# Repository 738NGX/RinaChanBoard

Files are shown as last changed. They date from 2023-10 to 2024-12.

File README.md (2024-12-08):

# 璃奈板Project
“璃奈板”出自日本万代南梦宫集团旗下全媒体音乐偶像企划《LoveLive!虹咲学园学园偶像同好会》，是登场角色天王寺璃奈制作的舞台道具，可以在表演时随歌曲自动变换表情来向台下观众传达情感。本项目遵循AGPL-3.0协议开源，致力于面向LoveLive!系列企划粉丝打造一款能够完全还原动画中功能的、更加贴合用户实际使用需求的璃奈板产品。

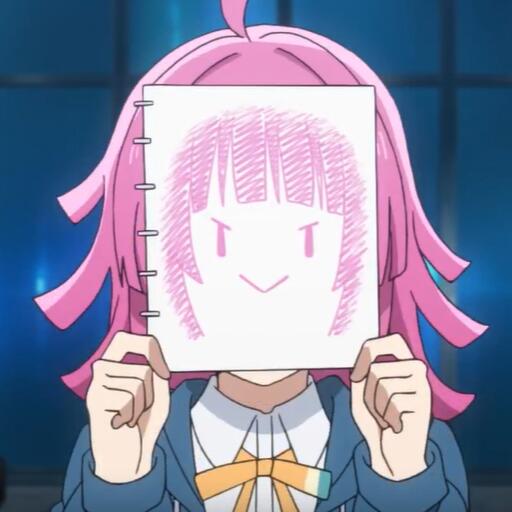
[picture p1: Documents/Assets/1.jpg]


## 🕊️ 项目进度

### 📝 计划中

- 下位机硬件驱动重写，着重性能提升。
- 3D外壳重建模。

### 🪲 进行中

- 文档补全中。
- Unity上位机（RinaChanBoardOperationCenter）编写中。
- 适用于ESP32的下位机（RinaChanBoardHardwareV2）编写中。

### ✅ 已完成

- 外壳3D打印试验。
- 主控、灯板PCB设计。
- 基于QT6.8.0的测试软件。
- ~~微信小程序上位机（RinaChanBoardOperationCenter.wechatapp）~~，已停止维护。
- ~~适用于ESP8266的下位机（RinaChanBoardHardware）~~，已停止维护。

## 🏠 文档导航

2. [总体设计](./Documents/2.总体设计.md)
3. [数据结构设计](./Documents/3.数据结构设计.md)
4. [通信报文设计](./Documents/4.通信报文设计.md)
5. [下位机系统功能设计](./Documents/5.下位机系统功能设计.md)
6. [上位机工具设计](./Documents/6.上位机工具设计.md)
7. [上位机组件设计](./Documents/7.上位机组件设计.md)
8. [上位机页面设计](./Documents/8.上位机页面设计.md)
9. [上位机资源数据](./Documents/9.上位机资源数据.md)

### 附录

- [附录1-口型同步](./Documents/附录1-口型同步.md)

## 📓 参考资料

(日本✌的开发博客)[NSmagnets - Qiita](https://qiita.com/NSmagnets)

(flyAkari版方案:ESP8266&Arduino+Android)[flyAkari/RinaChanBoard(github.com)](https://github.com/flyAkari/RinaChanBoard/tree/main)

(灯神)[我的颜色也是彩虹的一色！我与璃奈板 - 哔哩哔哩 (bilibili.com)](https://www.bilibili.com/read/cv9616845/)

(无敌扎蹄)[【天王寺科技】璃奈板的制作过程_哔哩哔哩_bilibili](https://www.bilibili.com/video/BV12b4y1t746/)

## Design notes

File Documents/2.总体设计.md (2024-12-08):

## 2. 总体设计

### 2.1 系统功能

整个项目系统可以被分为上位机和下位机两个子系统。每个子系统下又有各个细分模块。

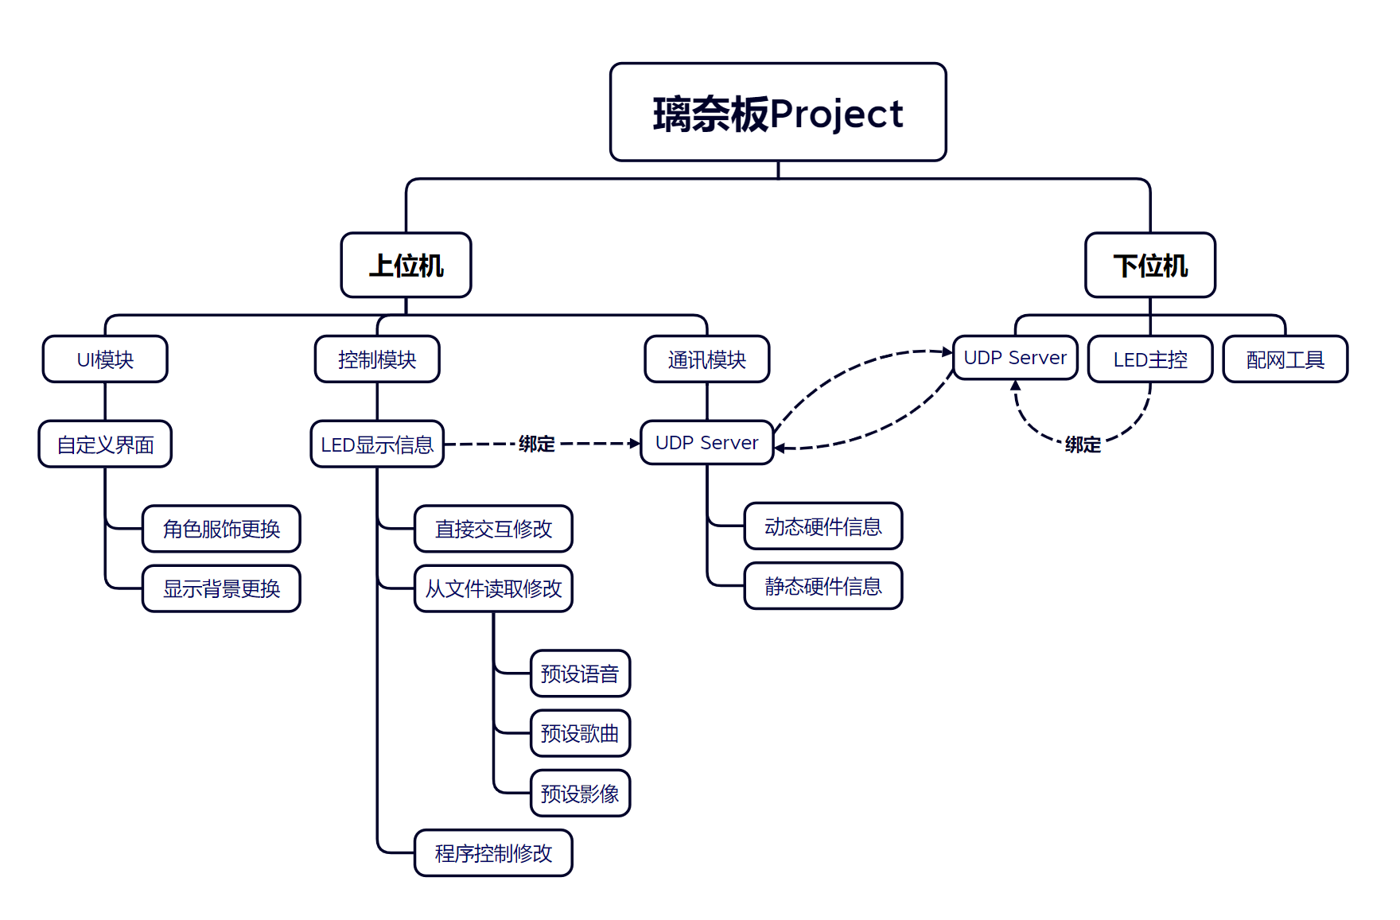
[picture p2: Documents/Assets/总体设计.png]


#### 2.1.1 上位机功能

实现上位机功能的载体为控制软件。

- **UI模块：**提供给用户自定义控制软件显示界面的功能。
- **控制模块：**提供了多种对LED显示信息的修改方法。
- **通讯模块：**提供了与下位机的通讯功能。

#### 2.1.2 下位机功能

实现下位机功能的载体为硬件驱动。测试软件亦可以模拟实现下位机的功能。

- **UDP Server：**提供与上位机的通讯功能。
- **LED主控：**提供对LED灯显示情况的控制功能。测试软件使用UI对LED灯显示情况进行模拟。
- **配网工具：**帮助下位机连接到指定的无线网络。测试软件直接使用主机网络的ip作为UDP Server地址，因而不包含此一功能。

### 2.2 系统软硬件平台

#### 2.2.1 系统开发平台

- **控制软件：**Unity 2022.3.15f1c1，API兼容级别`.NET Framework`直接使用或经过改写的第三方库如下：

    - **页面动画：**[Demigiant/dotween: A Unity C# animation engine. HOTween v2](https://github.com/Demigiant/dotween)
    - **口型同步：**[hecomi/uLipSync: MFCC-based LipSync plug-in for Unity using Job System and Burst Compiler](https://github.com/hecomi/uLipSync)

- **硬件驱动：**有第一代、第二代共两代驱动软件，分别适用于不同的硬件平台。硬件平台、板型、架构、使用库信息通过项目配置文件展示。

    - **RinaChanBoard Hardware：**PlatformIO Project

        ```ini
        [env:nodemcuv2]
        platform = espressif8266
        board = nodemcuv2
        framework = arduino
        monitor_speed = 9600
        lib_deps = 
        	fastled/FastLED@^3.6.0
        ```

    - **RinaChanBoard Hardware V2：**PlatformIO Project

        ```ini
        [env:esp32dev]
        platform = espressif32
        ;board = esp32dev
        board = esp32s3box
        framework = arduino
        monitor_speed = 115200
        monitor_rts = 0
        monitor_dtr = 0
        lib_deps = 
        	fastled/FastLED@^3.6.0
        	wnatth3/WiFiManager@^2.0.16-rc.2
        ```

- **测试软件：**C++20 & QT 6.8.0，使用Cmake编译（最低版本3.29）。

#### 2.2.2 系统运行平台

- **控制软件：**目前支持Windows和Android，计划支持iOS。

    | 操作系统                                    | 支持情况 | 备注                   |
    | ------------------------------------------- | -------- | ---------------------- |
    | Windows 7 (SP1+), Windows 10 and Windows 11 | ✅        |                        |
    | Android 10 或更高                           | ✅        | 目标架构为ARMv7和ARM64 |

- **硬件驱动：**两代硬件驱动的支持情况如下：

    | 驱动版本                  | Platform                 | Board               | 备注     |
    | ------------------------- | ------------------------ | ------------------- | -------- |
    | RinaChanBoard Hardware    | ESP8266（espressif8266） | nodemcuv2           | 不再维护 |
    | RinaChanBoard Hardware V2 | ESP32S（espressif32）    | esp32dev→esp32s3box |          |

- **测试软件：**Windows 7 (SP1+), Windows 10 and Windows 11。

### 2.3 关键技术

#### 2.3.1 无线通信

在本项目中，上位机和下位机之前的通讯使用**UDP协议**来完成。这是基于需要即时响应的需求，牺牲了一部分可靠性来换取更高的性能。基于硬件条件的限制，经过测试后，以**0.1s**作为UDP包发送和接收的最小间隔，称为1**帧（frame）**。UDP协议没有重传机制，当用户操作上位机发送离散控制信息时，需要用户自行确认硬件情况来检查包传送到位，如出现丢包需要用户重复操作来进行重传；当上位机程序发送连续控制信息时出现丢包不会进行重传，而是直接用后续的控制信息进行覆盖。

上位机和下位机需要在同一局域网下才能够进行通信，对应UDP Server的IP和端口情况如下表所示：

| 软件 | IP地址 | 端口 |
| --- | --- | ---- |
| 上位机-控制软件 | 主机本地IP地址 | 4321 |
| 下位机-硬件驱动 | 主控本地IP地址 | 1234 |
| 下位机-测试软件 | 主机本地IP地址 | 1234 |

具体的配网流程参见**[5.3 配网工具](./5.下位机系统功能设计)**章节；具体的上下位机通讯过程参见**[7.2 UDP服务](./7.上位机组件设计.md)**章节。

#### 2.3.2 口型同步

口型同步（LipSync）技术通过分析**梅尔倒谱系数（MFCC）**数据,解析音频中的元音信息（日语或汉语中的a、i、u、e、o），并且将其反应到璃奈板的口型上。在用户层面，该技术可以检测用户的麦克风输入来实时控制璃奈板的表情来模拟说话的效果。在开发者层面，该技术可以辅助编写时间轴文件，提升开发效率。

该部分内容较多，由于篇幅原因不在本篇文档展示，详情可查阅文档：**[附录1-口型同步](./附录1-口型同步.md)**。

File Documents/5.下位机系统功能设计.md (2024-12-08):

## 5. 下位机系统功能设计

实现下位机功能的载体为硬件驱动。测试软件亦可以模拟实现下位机的功能。本项目的下位机代码位于根目录的以下位置：

- ~~第一代硬件驱动：`RinaChanBoardHardware/RinaChanBoardHardware`~~ 弃用
- 第二代硬件驱动：`RinaChanBoardHardware/RinaChanBoardHardwareV2`
- 测试软件：`RinaChanBoardTester`

### 5.1 UDP Server

在硬件连接到网络后，下位机会自动在本地网络的1234端口启动一个UDP Server，准备监听从上位机发送的数据。监听的流程使用一个异步的协程`udpHandler`来实现，如下图所示：

```mermaid
sequenceDiagram
actor user as 用户 User
box 上位机
participant oc as 控制软件 OperationCenter
end
box 下位机
participant udp as UDP异步协程 udpHandler
participant leds as LED主控 leds
end
user->>oc: 用户控制上位机发送数据
oc->>udp:下位机接收来自上位机的数据包
activate udp
udp-->leds:handlePacket()开始
alt 包为PackTypeLen::FACE_FULL
    udp->>leds: 解码Face_Full报文并更新表情
else 包为PackTypeLen::FACE_LITE
    udp->>leds: 解码Face_Lite报文并更新表情
else 包为PackTypeLen::COLOR
    udp->>leds: 解码Color报文并更新颜色
else 包为PackTypeLen::BRIGHT
    udp->>leds: 解码Bright报文并更新亮度
else 包为PackTypeLen::REQUEST
    udp->>oc: 根据请求内容返回对应报文
end
udp-->leds:handlePacket()结束
deactivate udp
```

### 5.2 LED主控

UDP Server在判断出报文类型后，调用LED主控的函数来执行对应的操作，如下表所示：

| 报文 | 操作 |
| --- | --- |
| Face_Full报文/Face_Lite报文 | 解码为脸字符串后更新LED显示表情 |
| Color报文 | 解码为颜色数据后更新LED的显示颜色 |
| Bright报文 | 解码为亮度数据后更新LED的显示亮度 |
| 请求报文 | 将当前LED的对应显示信息编译为报文传回上位机 |

针对LED的控制主要依赖`<FastLED.h>`库。该库可以对所有灯珠的亮度进行整体控制，也可以对每个灯珠的颜色进行单独控制。该库中灯珠颜色的表示类型为`CRGB`，`CRGB::Black`表示灯珠熄灭，主要依靠这个来判断LED的开闭情况。

### 5.3 配网工具

硬件驱动借助了[tzapu/WiFiManager: ESP8266 WiFi Connection manager with web captive portal](https://github.com/tzapu/WiFiManager)库来帮助主控芯片连接到WIFI网络，配网的流程如下图所示：

```mermaid
sequenceDiagram
actor user as 用户 User
participant lan as 局域网 LAN
create participant main as 下位机主进程 Main
user->>main:硬件开机
participant flash as 主控闪存 Flash
main->>flash:查询是否存储了WIFI信息
alt 闪存中有存储WIFI信息
	main->>lan:尝试按照存储的WIFI名、密码连接到目标网络
	opt 连接成功
		main->lan:启用UDP Server监听
		Note over main,lan:成功连接，可以跳过后续配网流程
	end
else 进入配网流程
	loop 当配网未成功时
        create participant wm as 配网工具 WifiManager
        main->>wm:启用配网工具
        wm->>lan:扫描所有可以连接的WIFI网络
        create participant ap as 板载热点 AP
        wm->>ap:启用软AP热点
        wm->>ap:启用HTTP Server
        activate ap
        user->>ap:用户连接热点，选择WIFI并输入密码
        deactivate ap
        ap->>wm:记录用户输入信息
        destroy ap
        wm-xap:关闭软AP热点
        wm->>lan:根据用户输入信息尝试连接到目标网络
    end
    wm->>flash:存储WIFI信息以供下次开机时使用
    destroy wm
    main-xwm:结束配网
    main->lan:启用UDP Server监听
	Note over main,lan:成功连接
end
```

璃奈板硬件配备的网卡有两种模式：**基站模式（STA模式）**和**接入点模式（AP模式）**。STA模式下璃奈板与一般的主机一样连接到WIFI网络，并可以与同网络下的其他终端进行通信；AP模式下璃奈板自身会提供一个WIFI接入点供其他终端进行连接，承担类似于路由器或者手机热点的角色。璃奈板的配网逻辑基于这两种模式之间的切换。

璃奈板通电后首先进入到STA模式，尝试连接上次开机时连接到的网络。如果不能够成功连接，那么系统将会切换到AP模式，启动一个名为*RinaChanBoard*的WIFI热点，并且在`192.168.11.13`的地址启动一个HTTP Server作为配网的UI界面。当其他终端连接到该热点后即自动跳转到该页面。页面将会显示设备扫描到的所有可连接的WIFI网络（仅支持AP频段为**2.4GHz**频段的WIFI网络），随后用户可以直接选择并且输入密码信息。璃奈板确认WIFI名称和密码后会切换到STA模式尝试连接，如果成功连接，则配网流程结束，系统会存储下WIFI的名称和密码以供下次开机时再次连接使用；如果连接失败，系统切换回AP模式，重新开始配网流程。

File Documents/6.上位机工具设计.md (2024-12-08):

## 6. 上位机工具设计

在本项目中，所有的工具代码位于根目录`${OC}/Assets/Scripts/DataStructs`。

### 6.1 数据库工具`DatabaseTool`

静态类型`DatabaseTool`提供了一系列方法来将json文件序列化为实现了`IDatabase`接口的数据结构。json文件的序列化主要依赖`Newtonsoft.Json`库来实现。

#### 6.1.1 通用模板序列化函数

```c#
public static Dictionary<int, T> BuildDatabase<T>(string src) where T : IDatabase {...}
```

用户传入数据结构类型和json文件路径后，函数会返回一个静态字典数据库。字典的键为数据结构类型的`Id`属性，字典的值为数据结构类型本身。

#### 6.1.2 时间轴序列化函数

由于记录时间轴的json文件并不包含`Id`信息，所以序列化时间轴的函数需要调用媒体信息数据并从中获取`Id`作为字典的键。根据不同的媒体类型分别拆分成了三个独立的函数来实现功能：

```c#
public static Dictionary<int, TimeLine> BuildVoiceTimelineDatabase() {...}
public static Dictionary<int, TimeLine> BuildMusicTimelineDatabase() {...}
public static Dictionary<int, TimeLine> BuildVideoTimelineDatabase() {...}
```

函数的实现逻辑如下图所示：

```mermaid
flowchart LR
0([函数入口])-->1[调取媒体信息数据]-->2[遍历媒体信息]-->3[尝试根据媒体信息\n读取json文件]
3--读取成功-->4[构建时间轴数据\n将键值对写入字典]-->6[/遍历是否结束?/]
3--读取失败-->5[跳过该条媒体信息\n控制台记录日志]-->6--是-->7([返回字典结果])
6--否-->2
```

#### 6.1.3 ASCII序列化函数

```c#
public static Dictionary<string, Ascii> BuildAsciiDatabase() {...}
```

其实现逻辑上与通用模板序列化函数一致，区别在于其使用的键是字符`Symbol`而非`Id`，因而也单列一个函数。

### 6.2 媒体工具`MediaTool`

静态类型`MediaTool`主要保存了一系列媒体信息数据字典和时间轴数据字典，同时还提供了一个方法来将帧号转换为分秒格式的字符串。

#### 6.2.1 媒体信息数据字典

```c#
public static readonly Dictionary<int, VoiceInfo> voiceInfos;	// 语音信息
public static readonly Dictionary<int, MusicInfo> musicInfos;	// 歌曲信息
public static readonly Dictionary<int, VideoInfo> videoInfos;	// 影像信息
```

#### 6.2.2 时间轴数据字典

```c#
public static readonly Dictionary<int, TimeLine> voiceTimeLines;	// 语音时间轴
public static readonly Dictionary<int, TimeLine> musicTimeLines;	// 歌曲时间轴
public static readonly Dictionary<int, TimeLine> videoTimeLines;	// 影像时间轴
```

#### 6.2.3 时间戳转换函数

```c#
public static string ConvertFramesToTime(float frames) {...}
```

- 参数：帧号`frame`
- 返回：时间戳字符串

在播放歌曲和影像时用于进度条UI的数字时间戳显示。

### 6.3 LED工具`LedTool`

静态类型`LedTool`主要用于辅助实现一些灯光控制的功能。

#### 6.3.1 映射表`ledMap`

用于将`FaceString`的每一位映射到对应Id的LED灯珠上。映射过程在前文已有提及，不再重复阐释。

#### 6.3.2 预设颜色

预设颜色包括默认颜色以及LoveLive!五代团的所有角色、小组、团体应援色。数据分别存储在两个二维列表中：

- `colorName`：预设颜色对应的角色名或小组名；
- `colorValue`：预设颜色对应的十六进制RGB数值；

#### 6.3.3 点阵信息

点阵信息主要用于修改特定区域的LED灯珠显示情况，包括表情模块点阵`faceModules`和ASCII字符点阵`asciis`。

#### 6.3.4 转换函数

转换函数主要用于一些数据之间的互相转换。

- **十六进制/二进制字符串互转：**`HexToBinary`和`BinaryToHex`。
- **十六进制字符串/`Unity.Color`互转：**`HexToColor`和`ColorToHex`。
- **十六进制字符串/bytes数组互转：**`HexToBytes`和`BytesToHex`。

### 6.4 口型同步工具`RinaLipSync`

详情可查阅文档：**[附录1-口型同步](./附录1-口型同步.md)**。

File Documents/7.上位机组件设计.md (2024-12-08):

## 7. 上位机组件设计

在本项目中，所有的组件代码位于根目录`${OC}/Assets/Scripts/Components`。所有组件均继承自`MonoBehaviour`类。

### 7.1 LED组件`Leds`

该组件主要控制上位机上有关LED显示情况的UI部分。

#### 7.1.1 属性

| 属性名 | 类型 | 访问性 | 说明 |
| --- | --- | --- | --- |
| `CanCustom` | bool | public get; public set;  | 为true时可以单击对应的灯珠UI来切换开闭状态 |
| `WaitColorUpdate` | bool | public get; public set;  | 为true时触发页面颜色信息更新回调 |
| `Brightness` | int | public get; public set;  | 表示灯珠亮度 |
| `LedOnColor` | Color | public get; private set; | 表示灯珠开启的颜色 |
| `LedOffColor` | Color | private get; | 表示灯珠关闭的颜色 |
| `leds` | List | private get; | 灯珠UI列表 |
| `faceString` | StringBuilder | private get; | 脸字符串 |

#### 7.1.2 方法

```mermaid
flowchart TD
classDef extra fill:#fff;
classDef private fill:#ffa;

0[UpdateFaceModule\n更新表情模块]:::private
14(leds):::private
15(faceString):::private
0--修改-->14
0--修改-->15

1[UpdateColor\n更新LED显示颜色]--修改-->13(LedOnColor)
1--修改-->14
2[ClearFace\n清空显示表情]--修改-->14
2--修改-->15
3[UpdateFace\n根据Face更新表情显示]
3--依赖-->4[UpdateCheek\n更新脸颊模块]--依赖-->0
3--依赖-->5[UpdateLeftEye\n更新左眼模块]--依赖-->0
3--依赖-->6[UpdateRightEye\n更新右眼模块]--依赖-->0
3--依赖-->7[UpdateMouth\n更新嘴巴模块]--依赖-->0
8[SwitchLed\n切换单个LED开闭情况]--依赖-->16(LedTool.ledMap):::extra
0--依赖-->16
0--依赖-->17(LedTool.faceModules):::extra
8--修改-->14
8--修改-->15
9[UpdateLedsByString\n根据脸字符串更新表情显示]--依赖-->11[LedTool.HexToBinary]:::extra
9--修改-->14
9--修改-->15
10[EncodeFace\n将当前表情编码为脸字符串]--依赖-->12[LedTool.BinaryToHex]:::extra
10--依赖-->15
```

该组件的方法依赖和修改关系如上图所示，以下为图例说明，后文相关图片亦参照此图例：

- 直角矩形：表示方法
- 圆角矩形：表示属性
- 绿色：表示公有成员
- 黄色：表示私有成员
- 白色：表示外部成员

### 7.2 UDP服务`UdpServer`

该组件主要实现与下位机的通讯功能，几乎所有的模块都或多或少依赖该组件。由于UDP协议实际上没有如同TCP协议的建立连接过程，因而下文表述中的“连接”均为一种**伪连接**，代表UDP服务已经能够确定下位机的IP地址并且向该地址发送数据包，而不是真正意义上的TCP协议规定的连接。

#### 7.2.1 属性

| 属性名 | 类型 | 访问性 | 说明 |
| --- | --- | --- | --- |
| `IsConnected` | bool | public get; public set; | 为true时代表已经与下位机建立连接 |
| `LEDs` | Leds | public get; private set;  | 关联的LED组件 |
| `SendLiteFace` | bool | public get; private set;  | 在条件允许时使用Face_Lite报文代替Face_Full报文 |
| `Mutex` | bool | public get; private set;  | false时不允许对LEDs的亮度颜色数据进行修改 |
| `udpClient` | UdpClient  | private get; private set; | UDP客户端 |
| `localEndPoint` | IPEndPoint | private get; private set; | 本地连接点，用于广播查找下位机 |
| `remoteEndPoint` | IPEndPoint | private get; private set; | 远程连接点 |
| `manualConnectWindow` | Transform  | private get; private set; | 手动连接窗口，初始隐藏，需要时显示 |
| `connectInfo` | Text | private get; private set; | 用于UI显示连接情况 |
| `ipCheckText` | Text | private get; private set; | 手动连接时用于UI显示ip输入是否合法 |
| `remotePort` | int | private get; | 下位机端口，默认1234 |
| `localPort` | int | private get; | 上位机端口，默认4321 |
| `requestTimeout` | float | private get; | 请求超时时间，默认为1秒 |

#### 7.2.2 建立连接

与下位机建立连接的流程如下图所示：

```mermaid
sequenceDiagram
	actor user as 用户 User
	box UDP服务 udpServer
	participant sd as 扫描设备 ScanDevices
	participant mc as 手动连接 ManualConnect
	end
	participant lan as 局域网 LAN
	create participant hw as 下位机 Hardware
	lan-->hw:下位机配网
	user->>sd:发起连接请求
	activate sd
	sd->>lan:向局域网所有设备的1234端口发起广播信号查找
	alt 下位机接收到广播信号
		hw->>sd:下位机返回校验数据
		alt 校验通过
		sd->>user:告知已成功连接
		deactivate sd
		else 校验不通过
			sd->>mc:弹出手动连接选项
		end
	else 下位机未收到广播信号
		sd->>mc:弹出手动连接选项
	end
	activate mc
	Note over user,mc:此时系统弹出一个窗口选项供用户操作，用户可以选择继续手动连接或者稍后重试
	opt 手动连接
        user->>mc:用户输入下位机IP地址
        Note over mc,hw:用户可以选择尝试手动连接或者强制手动连接两种方式<br/>尝试手动连接会向输入的下位机IP地址再发送一次查找信号来进行校验<br/>强制手动连接不会进行校验，直接告知用户已成功连接
        opt 尝试手动连接
            mc->>hw:发送查找信号
            alt 收到查找信号
                hw->>mc:下位机返回校验数据，校验通过后尝试手动连接成功
            end
        end
        mc->>user:告知手动连接结果
	end
	deactivate mc
```

通常来说，与上位机设备在同一局域网内的下位机均可以通过广播信号被查找到，但是会存在包括但不限于以下两种情况，需要用户自行进行手动连接：

1. 局域网内的设备数量过多，导致下位机不能在请求超时时间（默认是1秒）内做出回应；
2. 当上位机设备提供热点时，通过广播不能查找到连接到该热点的下位机，这种情况也必须进行手动连接。具体情况可参考以下图像：

```mermaid
flowchart TD
subgraph 需要手动连接
7[璃奈板-下位机]-->6[设备A-热点/上位机]
end
subgraph 可以自动连接
0[路由器-热点]
1[设备A-上位机]-->0
2[璃奈板-下位机]-->0
3[设备B-热点]
4[设备A-上位机]-->3
5[璃奈板-下位机]-->3
end
```

#### 7.2.3 用户与程序访问控制

UDP服务与LED组件的行为高度绑定，用户和上位机程序其他函数进行访问控制遵循的流程如下图所示：

```mermaid
sequenceDiagram
	actor user as 用户 User
	participant oc as 上位机程序控制 OC
	box UDP服务 udpServer
	participant udp as UDP客户端 udpClient
	participant leds as LED组件 LEDs
	end
	user->>udp:发起建立连接请求
	create participant hw as 下位机 Hardware
	udp-->hw:与下位机建立连接并主动同步一次数据
	activate leds
	opt 同步数据操作
        user->>udp:发起操作将下位机数据同步至上位机
        activate udp
        udp->>hw:向下位机发送请求报文
        hw->>udp:根据请求报文类型返回对应的数据信息
        udp->>leds:根据下位机返回的数据信息修改LED组件
        deactivate udp
	end
	opt 用户自定义修改LED操作
		user->>leds:用户对表情、颜色、亮度进行自定义修改
		user->>udp:发起操作将上位机修改数据更新到下位机
		activate udp
		udp-->leds:获取当前LED组件信息并编码
        udp->>hw:向下位机发送信息报文
        deactivate udp
	end
	opt 用户操作程序按照程序预设控制LED
		user->>oc:用户操作
		oc->>leds:程序按照预设修改LED
		oc->>udp:发起操作将上位机修改数据更新到下位机
		activate udp
        udp-->leds:获取当前LED组件信息并编码
        udp->>hw:向下位机发送信息报文
        deactivate udp
	end
	user->>udp:发起断开连接请求
	deactivate leds
	destroy hw
	udp--xhw:与下位机断开连接
	
```

### 7.3 上位机UI皮肤管理`RinaChanDressManager`

该组件为上位机UI显示数据`RinaChanDress`的封装，提供接口给UI组件修改上位机UI显示情况。具体应用参考**[8.2 界面布局与UI皮肤更换](./8.上位机页面设计.md)**章节。

### 7.4 口型同步组件`RinaLipSync`

详情可查阅文档：**[附录1-口型同步](./附录1-口型同步.md)**。

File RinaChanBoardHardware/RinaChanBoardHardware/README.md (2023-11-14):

# 关于RinaChanBoard Hardware

这是为738NGX's RinaChanBoard特制的C++下位机小程序.

## 📝 技术相关

### 与上位机通讯方式

使用TCP协议,借助巴法云物联网平台实现上位机-下位机之间的通信.当前端发生用户交互时,上位机将适当的指令消息推送到用户选定的topic(即不同的控制机型),下位机接受到来自topic中继的消息后,驱动WS2812B LED灯珠,做出表情变化.

## 🕊️ 更新路线图

- 近期可能会考虑重写歌曲播放逻辑.现在的歌曲播放完全照搬语音的播放逻辑,但是歌曲至少得实现暂停的功能吧
    - 正在考虑的实施方案:程序每隔1帧的时间从主题拉取一次消息,如果最新一条消息为'pause',则提前跳出播放函数.

## ✅ 版本更新记录

加粗部分为重大更新.

| 版本号 | 版本记录 |
| --- | --- |
| 0.0.1  | 首个通讯测试版本,上位机与下位机之间可以进行正常的消息对发. |
| 0.0.2  | 为下位机引入了控制WS2812B的功能. |
| 0.0.3  | 下位机可以通过接受来自上位机的自定义表情消息,在本地解码成二位数组映射到WS2812B上. |
| 0.0.4  | 下位机可以通过接受来自上位机的预设语音播放消息,在本地调用播放预编译的表情数据. |
| 0.0.5  | 下位机可以通过接受来自上位机的预设歌曲播放消息,在本地调用播放预编译的表情数据. |
| 0.0.6  | 下位机可以向上位机发送当前正在显示的表情信息 |
| 0.0.7  | 重写颜色和亮度控制，下位机的灯珠颜色和亮度均可以通过亮度控制，默认颜色调整为#f971d4;增加了一段开机动画. |

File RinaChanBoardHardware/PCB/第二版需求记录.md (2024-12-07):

## RinaChanBoardHW 改2 需求记录
1. 5V输出疑似无法关断
2. 电池封装画反了
3. 数据口更改为2mm孔距
4. 加入指示灯
5. 需要修复拔电时电池升压芯片反应不过来会导致主控重启
6. (?)加入重置按钮

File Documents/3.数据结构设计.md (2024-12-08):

## 3. 数据结构设计

在本项目中，所有的数据结构代码位于根目录`${OC}/Assets/Scripts/DataStructs`。所有数据结构均可以被序列化和反序列化。（`${OC}`指代`RinaChanBoardOperationCenter`，后文同）

### 3.1 `IDatabase`接口

这个接口使得系统能够从json文件读取数据并序列化为静态字典数据库。接口提供的属性`Id`作为字典的键，而类型本身作为字典的值。仅在上位机中使用。

```c#
public interface IDatabase
{
    int Id { get; }
}
```

实现了该接口的数据结构如以下UML图所示：

```mermaid
classDiagram
class IDatabase{
    <<interface>>
    +Id
}
class FaceModule{
    +Id
    +Content
}
class TimeLine {
    +Id
    +Content
    -contentHash
    +GetFaceIndex()
}
class VoiceInfo {
    +Id
    +Content
}
class MusicInfo {
    +Id
    +Title
    +Cover
    +Artist
    +Description
}
class VideoInfo {
    +Id
    +Title
    +Cover
}
class Ascii {
    +Id
    +Symbol
    +Content
}

FaceModule..|>IDatabase
TimeLine..|>IDatabase
VoiceInfo..|>IDatabase
MusicInfo..|>IDatabase
VideoInfo..|>IDatabase
Ascii..|>IDatabase
```

### 3.2 LED数据

这一部分的数据结构主要用于控制LED灯阵的显示情况，在上下位机中均有使用。

#### 3.2.1 脸字符串`FaceString`

长度为288的字符串，用于直观展示所有LED灯的开闭状态，支持最大分辨率为16×18的LED矩阵。由于璃奈板硬件仅包含270颗灯珠，因而字符串的每一位通过以下映射表（以下位机为例，上位机为C#语法的`List<List<int>>`）来映射到灯珠的id：

```c++
const int led_map[][18]=
{
    { -1, -1, 38, 39, 70, 71,102,103,134,135,166,167,198,199,230,231, -1, -1},
    { -1, 10, 37, 40, 69, 72,101,104,133,136,165,168,197,200,229,232,259, -1},
    {  9, 11, 36, 41, 68, 73,100,105,132,137,164,169,196,201,228,233,258,260},
    {  8, 12, 35, 42, 67, 74, 99,106,131,138,163,170,195,202,227,234,257,261},
    {  7, 13, 34, 43, 66, 75, 98,107,130,139,162,171,194,203,226,235,256,262},
    {  6, 14, 33, 44, 65, 76, 97,108,129,140,161,172,193,204,225,236,255,263},
    {  5, 15, 32, 45, 64, 77, 96,109,128,141,160,173,192,205,224,237,254,264},
    {  4, 16, 31, 46, 63, 78, 95,110,127,142,159,174,191,206,223,238,253,265},
    {  3, 17, 30, 47, 62, 79, 94,111,126,143,158,175,190,207,222,239,252,266},
    {  2, 18, 29, 48, 61, 80, 93,112,125,144,157,176,189,208,221,240,251,267},
    {  1, 19, 28, 49, 60, 81, 92,113,124,145,156,177,188,209,220,241,250,268},
    {  0, 20, 27, 50, 59, 82, 91,114,123,146,155,178,187,210,219,242,249,269},
    { -1, 21, 26, 51, 58, 83, 90,115,122,147,154,179,186,211,218,243,248, -1},
    { -1, 22, 25, 52, 57, 84, 89,116,121,148,153,180,185,212,217,244,247, -1},
    { -1, 23, 24, 53, 56, 85, 88,117,120,149,152,181,184,213,216,245,246, -1},
    { -1, -1, -1, 54, 55, 86, 87,118,119,150,151,182,183,214,215, -1, -1, -1},
};
```

映射公式为：

- 下位机

    ```c++
    if (led_map[i / 18][i % 18] == -1) return;
    leds[led_map[i / 18][i % 18]] = face_string[i] == '1' ? color : CRGB::Black
    ```

- 上位机

    ```c#
    if (LedTool.ledMap[i / 18][i % 18] == -1) return;
    leds[LedTool.ledMap[i / 18][i % 18]].color = faceString[i] == '1' ? LedOnColor : LedOffColor
    ```

#### 3.2.2 颜色数据`Color`

以RGB的形式用于直观展示所有LED灯的显示颜色。在下位机中使用三个`unsigned int`数储存，并在需要时构造成`CRGB`类型来使用；在上位机中，使用`UnityEngine.Color`类型来储存和使用。

#### 3.2.3 亮度数据`Bright`

以0-255之间的整型数来表示灯珠的显示亮度，在上下位机中均使用`int`数来储存。

虽然技术上能够支持0-255的亮度区间，但是基于用户佩戴体验、电池电量续航、电路安全等多方面因素考虑，最高只支持亮度为128的亮度值。同时为了简化操作，上位机只提供了四档的亮度调节：

| 亮度名 | 亮度值 |
| --- | --- |
| 正常 | 16 |
| 輝く | 32 |
| 眩しい | 64 |
| 光害 | 128 |

这是由于在实际测试中发现针对亮度的控制需求不必像颜色那样细节（比如亮度值16和亮度值17实际上并没有什么区别），因而仅依靠四档的亮度已经能够覆盖大部分的使用场景。默认情况下使用正常的亮度值16已经足够使用，只有在外部环境较亮时才会用到更高的亮度。更何况更高的亮度也会使得佩戴者的眼部感到不适。

### 3.3 表情数据

虽然使用`FaceString`已经可以用来表示璃奈板的显示表情了，但是冗长的字符串显然会增加开发压力。因而在上位机中引入了表情数据结构来呈现璃奈板的现实情况。

#### 3.3.1 表情模块`FaceModule`

表情模块是表情的基本组成元素。分为以下四种类型：

- **左眼（Leye）：**图中红色部分，行0-7，列0-7；
- **右眼（Reye）：**图中蓝色部分，行0-7；列10-17；
- **嘴巴（Mouth）：**图中黄色部分，行8-15；列5-12；
- **脸颊（Cheek）：**图中绿色部分，行8-11；列0-3 & 14-17；

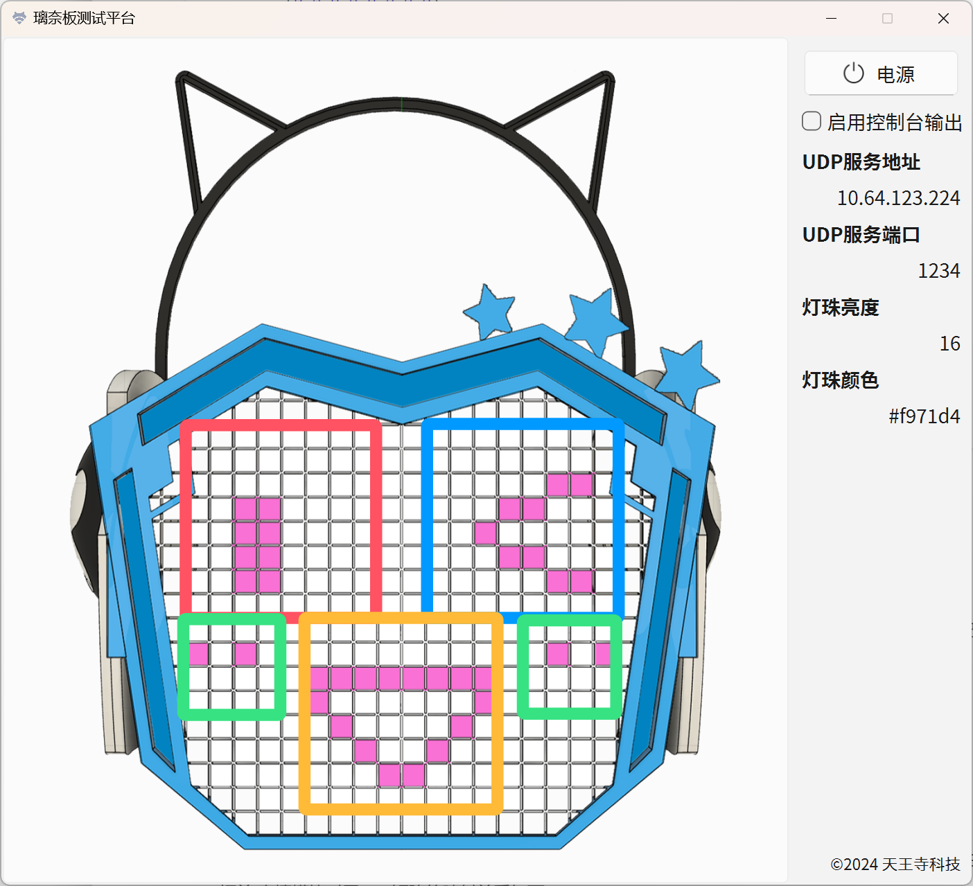
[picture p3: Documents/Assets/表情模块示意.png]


`FaceModule`类型实现了`IDataBase`接口，可以从以下格式的json文件中读取并序列化为字典数据库：

```json
[
    {
        "id": 0,
        "content": [
            [0,0,0,0,0,0,0,0],
            [0,0,0,0,0,0,0,0],
            [0,0,0,0,0,0,0,0],
            [0,0,0,0,0,0,0,0],
            [0,0,0,0,0,0,0,0],
            [0,0,0,0,0,0,0,0],
            [0,0,0,0,0,0,0,0],
            [0,0,0,0,0,0,0,0]
        ]
    },
    {
        "id": 400,
        "content": [
            [0,0,0,0],
            [0,0,0,0],
            [0,0,0,0],
            [0,0,0,0]
        ]
    }
]
```

- **id**是表情模块的唯一标识符，0代表空表情；101-199范围内代表左眼表情；201-299范围内代表右眼表情；301-399范围内代表嘴巴表情；400-499范围内代表脸颊表情（400为空脸颊）；
- **content**代表对应模块LED的实际显示情况，`content[i][j] = n`表示在该表情模块第i行第j列的LED灯的开闭状态为`n`，其中`n=1`代表LED灯开，`n=0`代表LED灯关。左眼、右眼、嘴巴的content大小都是8×8，而脸颊是4×4。脸颊的显示是对称的，json文件记录的是右眼同侧脸颊的显示情况，左眼同侧脸颊的现实情况为文件记录的镜像。

#### 3.3.2 表情`Face`

通过表情模块的组合，就可以构成表情。`Face`类型不实现`IDatabase`接口，但是其依然可以被以下json格式的内容反序列化，从而辅助构造其他相关的数据结构：

```json
{ "leye": 101, "reye": 201, "mouth": 303, "cheek": 400 }
```

其中`leye`代表左眼id，`reye`代表右眼id，`mouth`代表嘴巴id，`cheek`代表脸颊id。

### 3.4 时间轴数据

将一串表情串联起来并标上时间戳（帧号），就构成了时间轴。通过时间轴，上位机可以持续向下位机发出表情控制信息。

#### 3.4.1 时间轴单元`TimeLineUnit`

时间轴单元的构成为帧号+表情。两者的组合表示了在当前帧下应当显示的表情。`TimeLineUnit`类型不实现`IDatabase`接口，但是其依然可以被以下json格式的内容反序列化，从而辅助构造其他相关的数据结构：

```json
{
    "frame": 0,
    "face": { "leye": 101, "reye": 201, "mouth": 303, "cheek": 400 }
}
```

其中`frame`表示帧号，`face`表示表情。

#### 3.4.2 时间轴`TimeLine`

`TimeLine`类型实现了`IDataBase`接口，可以从以下格式的json文件中读取并序列化为字典数据库：

```json
[
    {
        "frame": 0,
        "face": { "leye": 102, "reye": 202, "mouth": 302, "cheek": 400 }
    },
    {
        "frame": 20,
        "face": { "leye": 101, "reye": 201, "mouth": 326, "cheek": 400 }
    }
]
```

但是时间轴类型的构造过程比其他实现了`IDataBase`接口的类型要复杂，因为上述的json的文件并没有提供时间轴的标识信息。时间轴类型包含了以下部分：

```c#
public class TimeLine : IDatabase
{
    public int Id { get; }
    public List<TimeLineUnit> Content { get; }
    private readonly Dictionary<int,int> contentHash = new();
    public TimeLine(int id, List<TimeLineUnit> content) {...}
    public int? GetFaceIndex(int frame) {...}
}
```

其中由json文件序列化的是`Content`部分，而`Id`作为标识符由媒体信息数据提供，时间轴类型的具体构造过程参考**[6.1 数据库工具](./6.上位机工具设计.md)**章节。另外类型包含了一个`GetFaceIndex`方法，可以通过查询帧号来返回时间轴单元在`Content`中的索引，这个方法依赖字典`contentHash`来实现，配合计数器使用可以防止发送重复的表情，节约性能开销。

### 3.5 媒体信息数据

媒体信息类型都实现了`IDataBase`接口，可以从json文件中读取并序列化为字典数据库。

#### 3.5.1 语音信息`VoiceInfo`

记录预设语音的相关信息，包含以下成员：

- **Id：**预设语音的唯一标识符。
- **Content：**语音的文字内容，用于UI界面显示。

#### 3.5.2 歌曲信息`MusicInfo`

记录预设歌曲的相关信息，包含以下成员：

- **Id：**预设歌曲的唯一标识符。
- **Title：**歌曲的标题，用于UI界面显示。
- **Cover：**歌曲的文件标识符，用于定位封面，音频源，时间轴等信息。
- **Artist：**歌曲的演唱者，用于UI界面显示。
- **Description：**歌曲的描述信息，用于UI界面显示。

#### 3.53 影像信息`VideoInfo`

记录预设影像的相关信息，包含以下成员：

- **Id：**预设影像的唯一标识符。
- **Title：**影像的标题，用于UI界面显示。
- **Cover：**影像的文件标识符，用于定位视频源，时间轴等信息。

### 3.6 其他类型数据

#### 3.6.1 上位机UI皮肤显示数据`RinaChanDress`

用于存储上位机的UI皮肤显示信息，具体应用参考**[8.2 界面布局与UI皮肤更换](./8.上位机页面设计.md)**章节。

#### 3.6.2 滚动文字字符数据`Ascii`

`Ascii`类型实现了`IDataBase`接口，可以从json文件中读取并序列化为字典数据库。主体为点阵ASCII字符用于辅助实现滚动文字功能（具体参见**[8.8 更多控制页面](./8.上位机页面设计.md)**章节）。结构上类似于`FaceModule`，包含以下成员：

- **Id：**滚动文字字符的唯一标识符，与ASCII的值对应。
- **Symbol：**对应的ASCII字符。
- **Content：**点阵数据，大小为5×7。

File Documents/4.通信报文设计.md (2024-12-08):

## 4. 通讯报文设计

本项目中通讯报文全部以`Hex`格式进行发送，与`Text`格式相比能至少节约一半的包大小，降低通讯压力与丢包概率，从而在高频通信时能够获得更好的性能表现。

### 4.1 状态报文

状态报文主要用于在上下位机之间更新、同步状态信息。主要依靠报文大小来区分不同类型的状态报文。

#### 4.1.1 Face_Full报文

**大小：36字节**

由于`FaceString`的长度为288，超过了UDP协议256个字节的传输上限，因而需要对齐进行一次压缩。因为原本脸字符串表示的是二进制数，因而简单的压缩方式就是将其压缩为十六进制数。压缩完后的Face_Full报文大小为36个字节，为脸字符串的八分之一。

举例: `0x00000000000000c00c30030c00c30030000000000000003f000840012000300000000000`

#### 4.1.2 Face_Lite报文

**大小：4字节**

在高速变换表情时为了降低通讯压力提升性能，针对单纯的由表情模块组合成的表情可以使用更简单的报文。每个表情模块的Id占用一个字节，这样只需要使用4个字节就可以表示整个表情，大小占用为正常Face_Full报文的九分之一。

举例：`0x04050600`，对应的表情模块id为左眼104，右眼204，嘴巴306，脸颊400。

#### 4.1.3 Color报文

**大小：3字节**

十六进制格式的RGB颜色。通过颜色数据`Color`编码而来，也可以解码为颜色数据。

举例: `0xf971d4`

#### 4.1.4 Bright报文

**长度：1字节**

十六进制的亮度值。通过亮度数据`Bright`编码而来，也可以解码为亮度数据。

举例: `0x80`

### 4.2 请求报文

由于下位机不会主动向上位机发送状态报文，因而需要上位机先发起一个请求。下位机收到请求报文后，再给上位机返回对应的状态报文。请求报文的长度均为**2字节**，需要完全匹配来区分。

#### 4.2.1 Face请求报文

**匹配: `0x1001`**

上位机向下位机发起脸字符串`FaceString`同步请求，下位机将当前LED颜色编码为Face_Full报文发回上位机。

#### 4.2.2 Color请求报文

**匹配: `0x1002`**

上位机向下位机发起颜色数据`Color`同步请求，下位机将当前LED颜色编码为Color报文发回上位机。

#### 4.2.3 Bright请求报文

**匹配: `0x1003`**

上位机向下位机发起亮度数据`Bright`同步请求，下位机将当前LED颜色编码为Bright报文发回上位机。

#### 4.2.4 Version请求报文

**匹配: `0x1003`**

上位机向下位机发起固件版本同步请求，下位机将当前固件版本发回上位机。

#### 4.2.4 Battery请求报文

**匹配: `0x1005`**

上位机向下位机发起电池电压同步请求，下位机将当前电池电压发回上位机。

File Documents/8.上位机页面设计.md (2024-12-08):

## 8. 上位机页面设计

在本项目中，所有的页面代码位于根目录`${OC}/Assets/Scripts/Pages`。

### 8.1 `IPage`类

本项目中所有的页面组件均继承此类型：

```c#
public class IPage : MonoBehaviour
{
    public Transform MainTransform { get; protected set; }
}
```

页面的脚本在本项目中通常并非绑定在页面组件本身，而是绑定在页面组件的父组件上（这样可以保证一些数据不会在页面隐藏时被销毁或重置），`MainTransform`的作用就是定位到页面组件本身，只需要在初始化时进行一次定位即可而不需要每次调用时重复搜索定位，提升性能。

### 8.2 界面布局与UI皮肤更换

上位机的界面布局如下图所示：

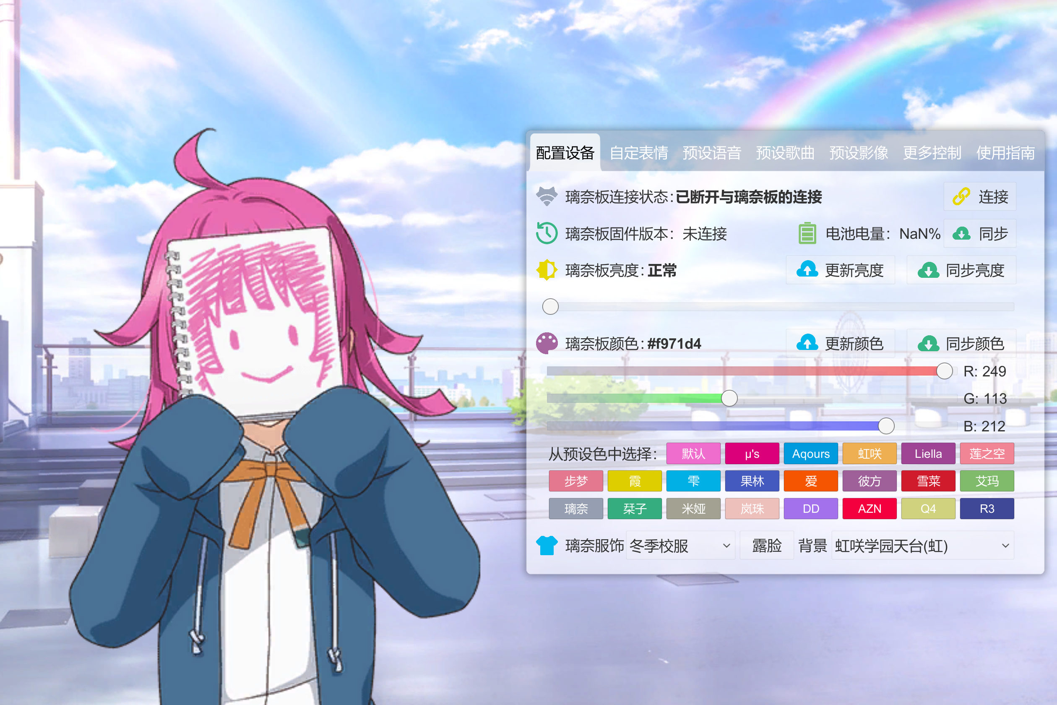
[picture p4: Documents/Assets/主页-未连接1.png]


屏幕左侧为璃奈的立绘，右侧为采用了亚克力材质设计的软件控制面板。通过组件`RinaChanDressManager`可以实现对璃奈立绘的服饰、是否露脸以及显示背景进行修改：

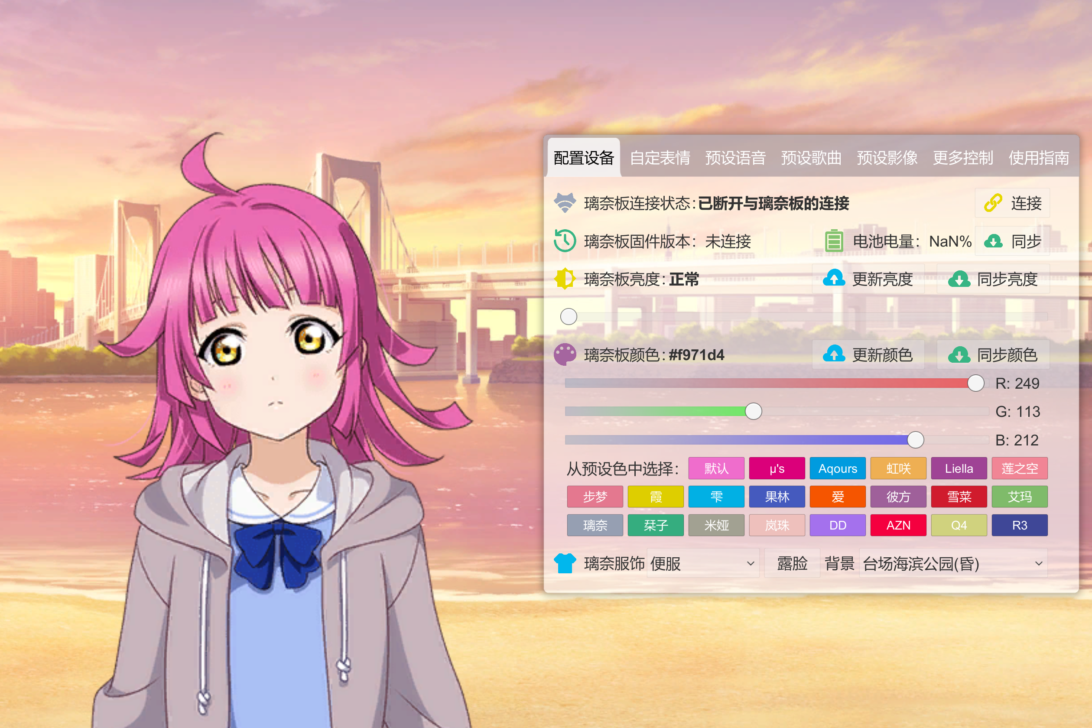
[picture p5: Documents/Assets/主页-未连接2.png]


### 8.3 配置设备页面

在该页面点击控制面板右上角的连接按钮，系统会自动开始在局域网内查找下位机。如果在请求超时时间（默认1秒）内不能查找到，系统弹出手动连接窗口，用户需要选择进行手动连接或稍后再试：

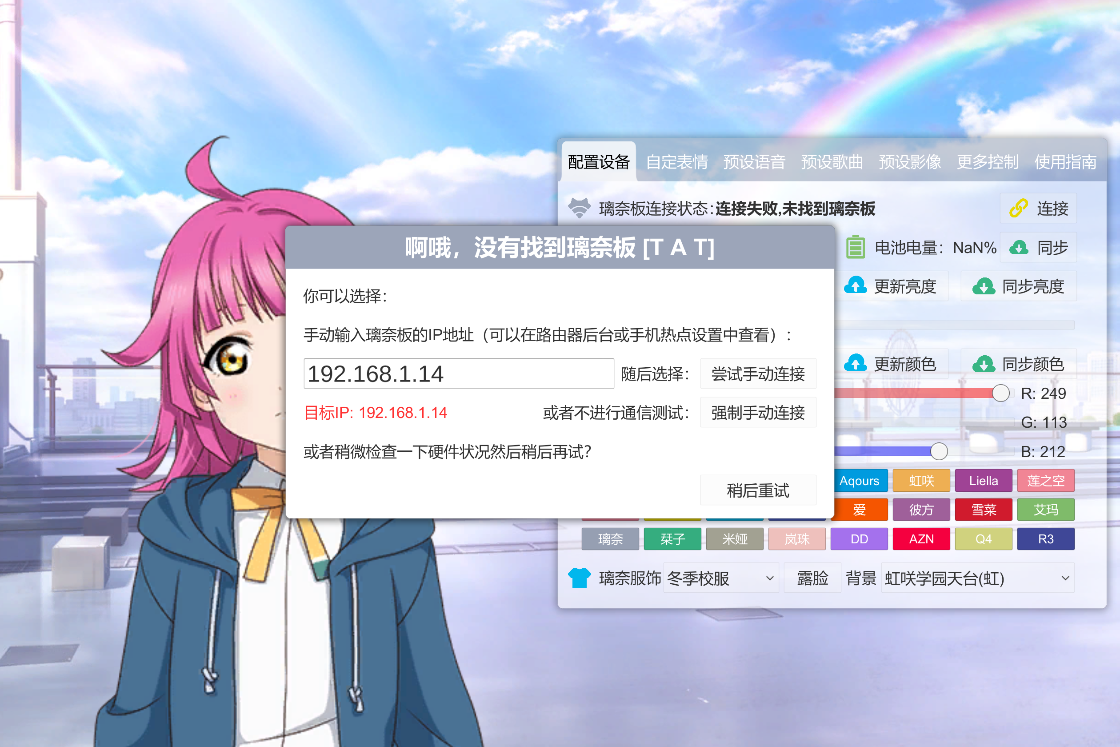
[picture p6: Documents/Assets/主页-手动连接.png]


如果成功与下位机建立连接，璃奈立绘脸上会出现璃奈板UI，页面变为如下图所示：

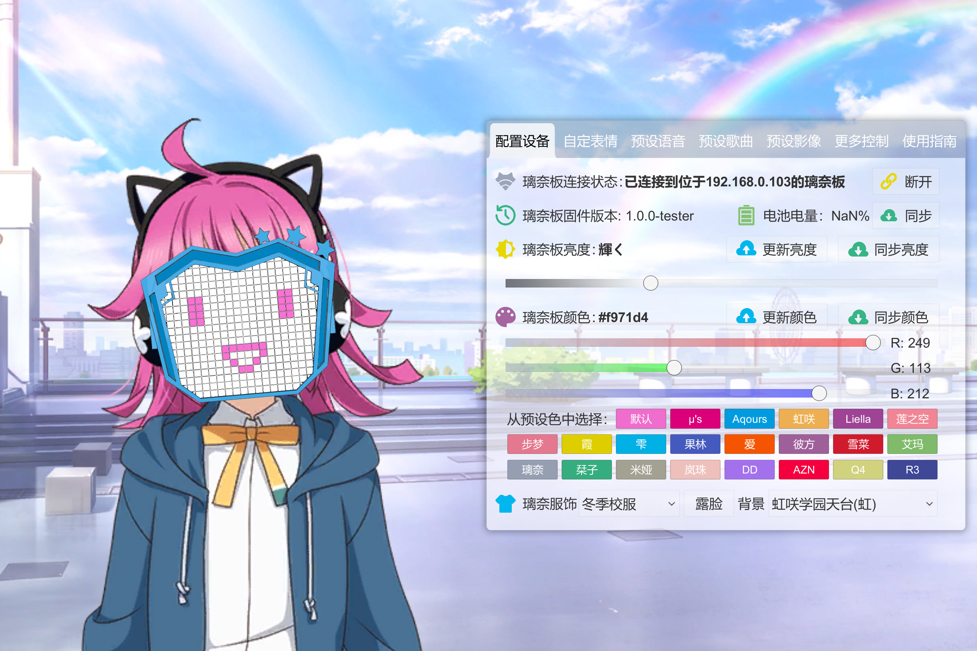
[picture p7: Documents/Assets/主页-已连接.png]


该页面会显示璃奈板的IP地址、固件版本、电池电量、LED亮度、LED颜色等各项信息，用户也可以通过该页面来修改下位机的LED亮度、LED颜色。每次上位机本地修改亮度、颜色后，需要点击对应的更新按钮将修改内容发送到下位机后修改方可生效。点击对应的同步按钮可以将当前的上位机本地状态修改为当前下位机的状态。

### 8.4 自定表情页面

该页面只有当上位机连接到璃奈板后才能进入。进入该页面时，左侧璃奈立绘消失，璃奈板UI会放大以供用户点击修改。

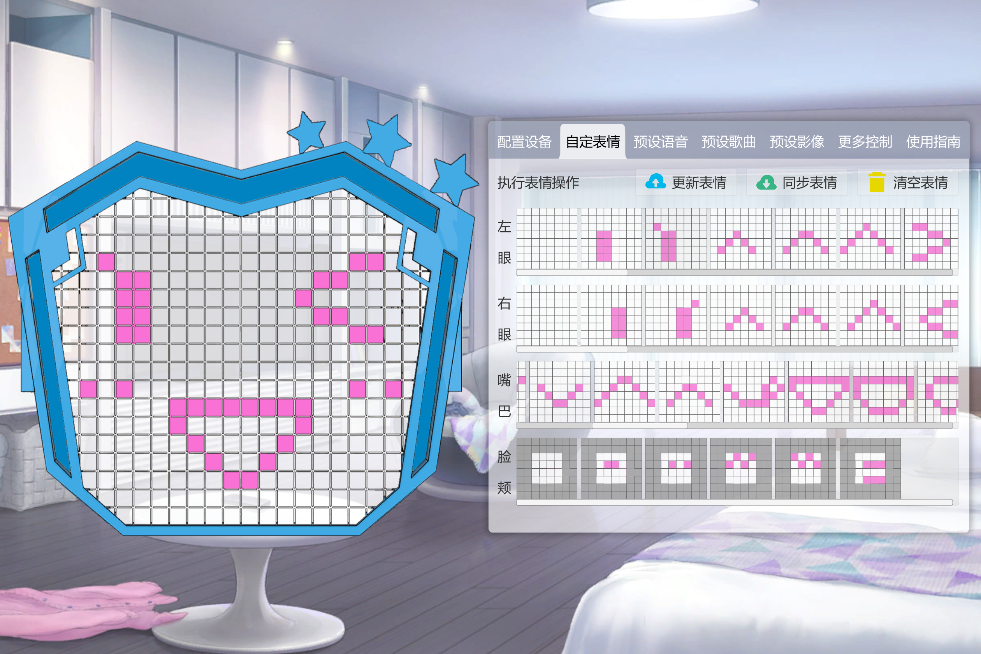
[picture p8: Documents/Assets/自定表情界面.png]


用户可以直接点击方格来改变LED灯珠的开闭状态，也可以在控制面板上选择已经预设好的表情模块来组合表情。每次上位机本地修改表情后，需要点击对应的更新按钮将修改内容发送到下位机后修改方可生效。点击对应的同步按钮可以将当前的上位机本地状态修改为当前下位机的状态。

### 8.5 预设语音页面

该页面只有当上位机连接到璃奈板后才能进入。

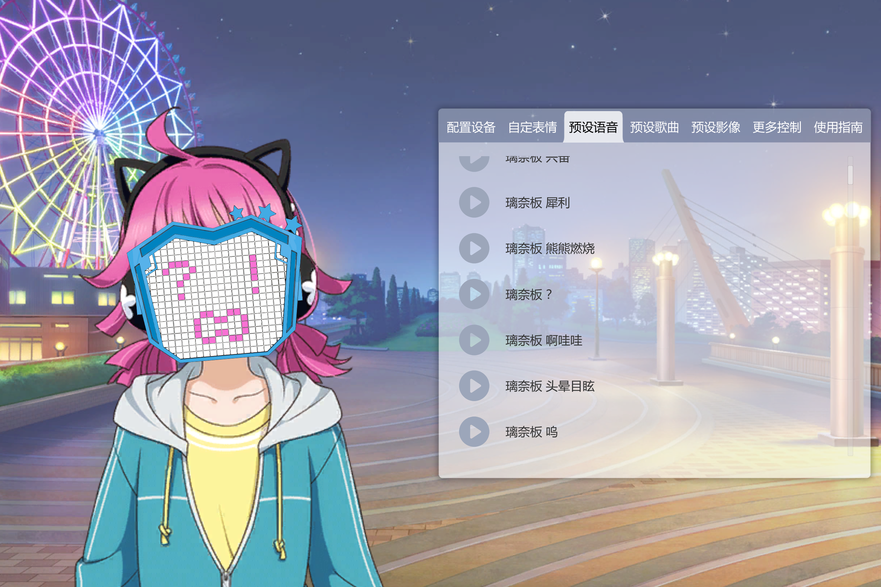
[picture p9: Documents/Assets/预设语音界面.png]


可以点击控制面板上各条语音文字左侧的播放按钮来播放预设语音，璃奈板的表情会随之产生变化。播放预设语音时启用互斥锁，此时不能够切换到其他页面。

### 8.6 预设歌曲页面

该页面只有当上位机连接到璃奈板后才能进入。

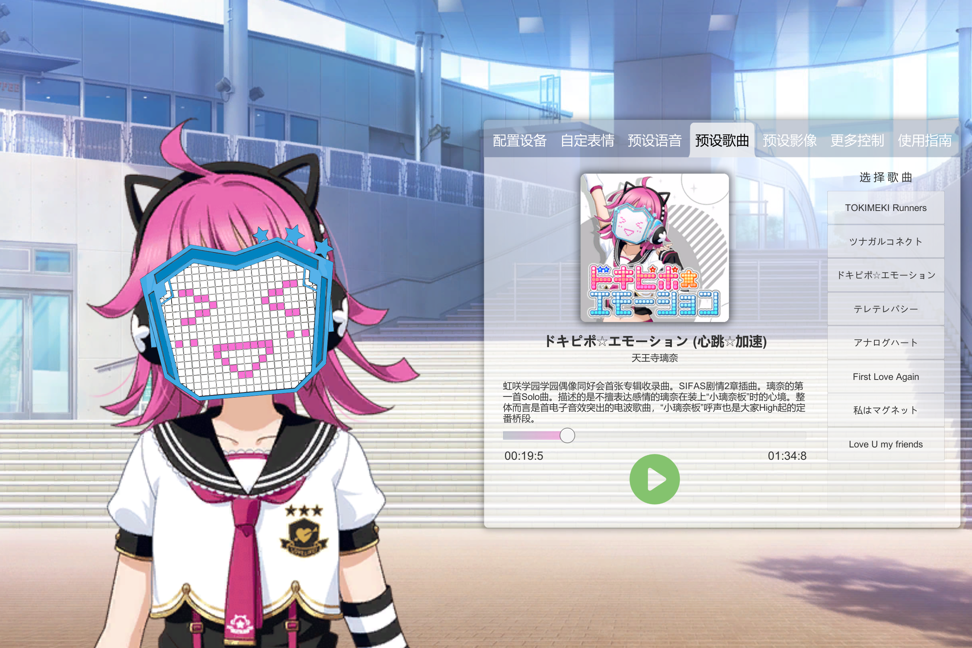
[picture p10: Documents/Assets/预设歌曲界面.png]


可以在控制面板的右侧边栏选择预设歌曲随后点击播放按钮播放，璃奈板的表情会随之产生变化。播放预设歌曲时启用互斥锁，不能切换歌曲、拖动进度条、切换页面。

### 8.7 预设影像页面

该页面只有当上位机连接到璃奈板后才能进入。

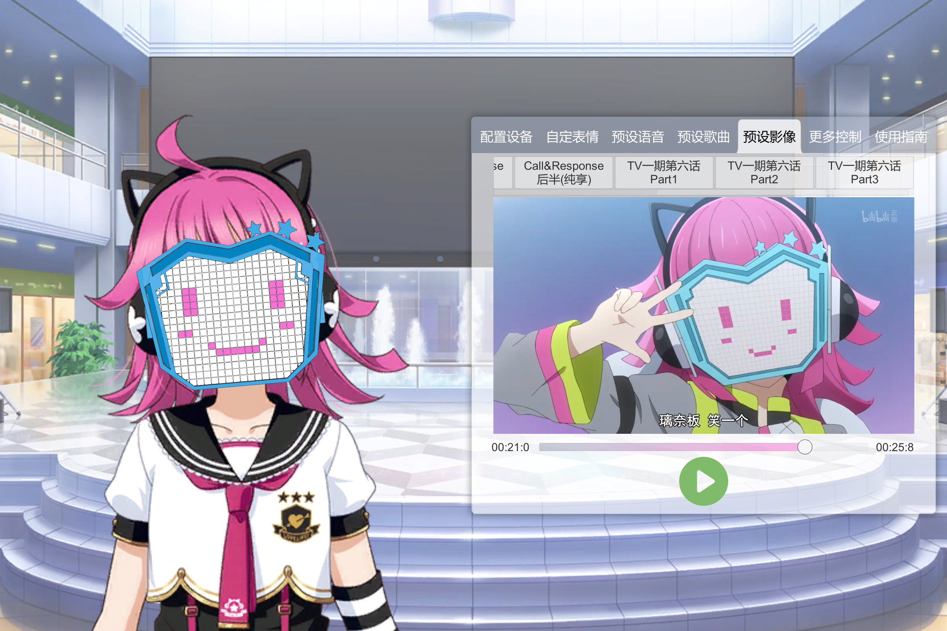
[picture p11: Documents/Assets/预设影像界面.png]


可以在控制面板的顶栏选择预设影像随后点击播放按钮播放，璃奈板的表情会随之产生变化。播放预设影像时启用互斥锁，不能切换影像、拖动进度条、切换页面。

### 8.8 更多控制页面

该页面只有当上位机连接到璃奈板后才能进入。该页面分为若干个子页面，进入子页面后启用互斥锁，不能切换页面。

#### 8.8.1 播放滚动文字

该页面支持发送一条最大长度为30的ASCII字符串到璃奈板，璃奈板滚动播放该字符串。

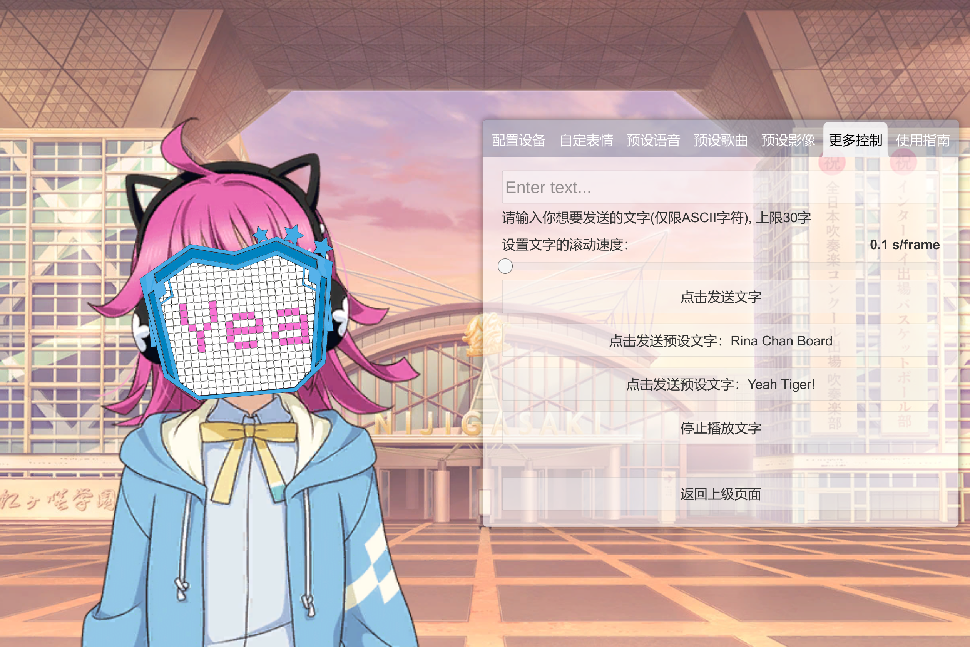
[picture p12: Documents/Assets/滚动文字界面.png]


包含一个可以输入文字的输入框、滚动速度调节滑动条、发送按钮；同时提供了两条常用预设文字的快捷发送按钮。播放滚动文字时启用互斥锁，不能编辑输入框、调节播放速度、返回上级页面。可以按停止播放文字按钮中断播放。

#### 8.8.2 小游戏

该页面支持与璃奈板玩一些互动小游戏，目前仅试装了猜拳游戏作为示例。

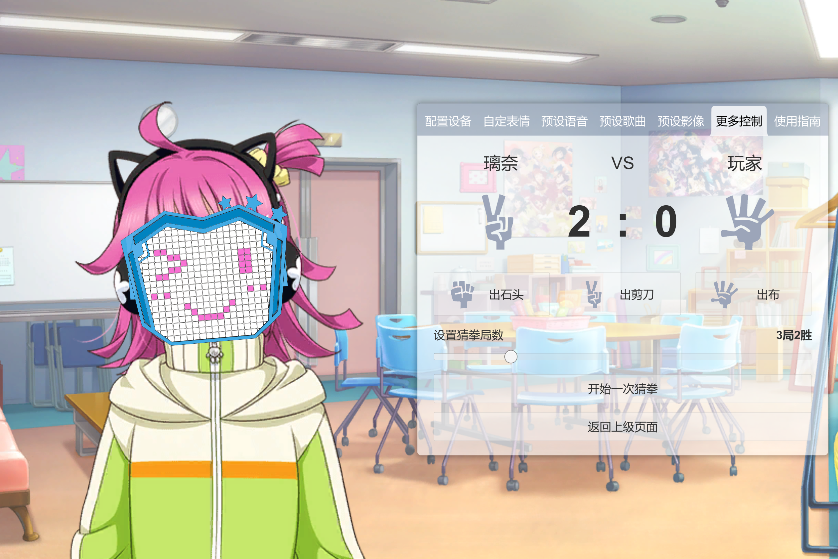
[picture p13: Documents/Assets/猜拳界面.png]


开始一局游戏后会启用互斥锁，不能修改游戏设置、返回上级页面。可以中断游戏。

#### 8.8.3 口型同步

该页面用于展示口型同步功能，详情可查阅文档：**[附录1-口型同步](./附录1-口型同步.md)**。

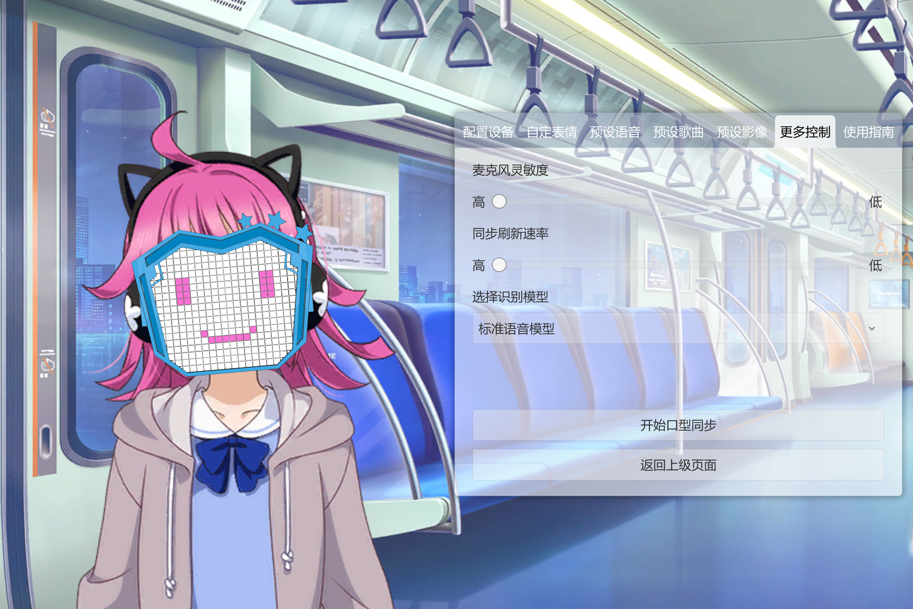
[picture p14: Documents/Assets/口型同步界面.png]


用户的可选项为调节麦克风灵敏度（影响最低触发口型同步的音量）、同步刷新速率（影响表情变化速度）、识别模型（包括标准、男声、女声、动漫四种预设模型）。开始口型同步后启用互斥锁，不能修改选项、返回上级页面。

### 8.9 使用指南页面

该页面上半部分为软件的一些使用指南说明，下半部分为项目Logo和所有开发成员、支持成员的展示。

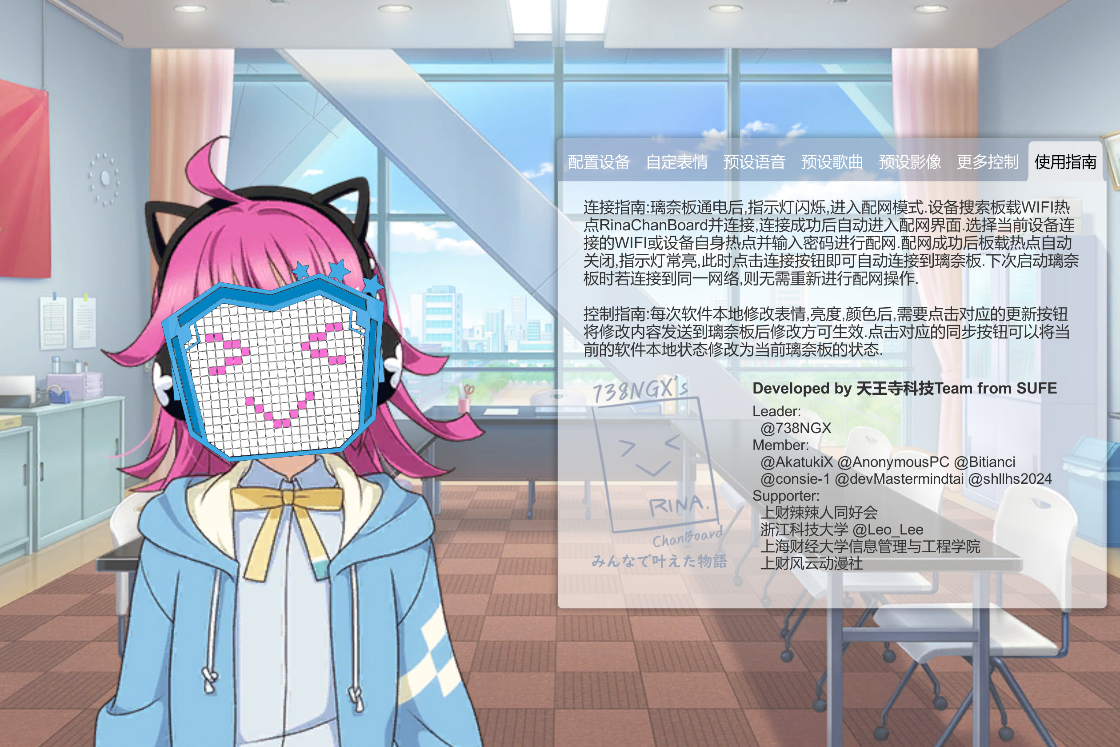
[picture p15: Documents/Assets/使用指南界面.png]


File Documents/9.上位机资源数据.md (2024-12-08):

## 9. 上位机资源数据

本项目中所有资源数据位于根目录`${OC}/Assets/Resources`

### 9.1 文本资源数据

文本数据均以json格式保存在`${OC}/Assets/Resources/Database`。包括点阵数据、媒体信息数据、媒体时间轴数据等。

### 9.2 媒体资源数据

媒体资源数据包括图片数据`Image`，语音数据`Voice`，歌曲数据`Music`，影像数据`Video`，分别存储在资源数据根目录对应的文件夹下。

### 9.3 口型同步资源数据

口型同步使用的资源数据为预设识别模型，存储在资源数据根目录的`LipSyncProfile`文件夹下。

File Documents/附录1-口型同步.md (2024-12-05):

# 口型同步 LipSync

## 1. 概述 Overview

口型同步(LipSync)技术通过分析梅尔倒谱系数(MFCC)数据,解析音频中的元音信息(日语或汉语中的a,i,u,e,o),并且将其反应到璃奈板的口型上.在用户层面,该技术可以检测用户的麦克风输入来实时控制璃奈板的表情来模拟说话的效果.在开发者层面,该技术可以辅助编写时间轴文件,提升开发效率.

>在声音处理领域中,**梅尔频率倒谱**(Mel-Frequency Cepstrum)是基于声音频率的非线性[梅尔刻度](https://zh.wikipedia.org/wiki/梅尔刻度)(mel scale)的[对数](https://zh.wikipedia.org/wiki/對數)能量频谱的线性变换.
>
>**梅尔频率倒谱系数** (**Mel-Frequency Cepstral Coefficients,MFCCs**)就是组成梅尔频率倒谱的系数.它衍生自音讯片段的[倒频谱](https://zh.wikipedia.org/wiki/倒頻譜)(cepstrum).倒谱和梅尔频率倒谱的区别在于,梅尔频率倒谱的频带划分是在[梅尔刻度](https://zh.wikipedia.org/wiki/梅尔刻度)上等距划分的,它比用于正常的对数[倒频谱](https://zh.wikipedia.org/wiki/倒頻譜)中的线性间隔的频带更能近似人类的听觉系统. 这样的非线性表示,可以在多个领域中使声音信号有更好的表示.例如在[音讯压缩](https://zh.wikipedia.org/wiki/音訊壓縮)中.
>
>梅尔频率倒谱系数(MFCC)广泛被应用于[语音识别](https://zh.wikipedia.org/wiki/語音識別)的功能.他们由Davis和Mermelstein在1980年代提出,并在其后持续是最先进的技术之一.在MFCC之前,线性预测系数(LPCS)和线性预测倒谱系数(LPCCs)是自动语音识别的的主流方法.
>
>
>MFCC通常有以下之过程:
>
>1. 将一段语音信号分解为多个[讯框](https://zh.wikipedia.org/wiki/訊框).
>2. 将语音信号[预强化](https://zh.wikipedia.org/w/index.php?title=預強化&action=edit&redlink=1),通过一个[高通滤波器](https://zh.wikipedia.org/wiki/高通濾波器).
>3. 进行[傅立叶变换](https://zh.wikipedia.org/wiki/傅立叶变换),将信号变换至频域.
>4. 将每个[讯框](https://zh.wikipedia.org/wiki/訊框)获得的频谱通过梅尔滤波器(三角重叠窗口),得到[梅尔刻度](https://zh.wikipedia.org/wiki/梅尔刻度).
>5. 在每个梅尔刻度上提取[对数](https://zh.wikipedia.org/wiki/對數)能量.
>6. 对上面获得的结果进行[离散余弦变换](https://zh.wikipedia.org/wiki/離散餘弦轉換),变换到[倒频谱](https://zh.wikipedia.org/wiki/倒頻譜)域.
>7. MFCC就是这个[倒频谱](https://zh.wikipedia.org/wiki/倒頻譜)图的幅度(amplitudes).一般使用12个系数,与讯框能量叠加得13维的系数.
>
>from [梅尔频率倒谱系数 - 维基百科,自由的百科全书](https://zh.wikipedia.org/wiki/梅尔频率倒谱系数)

## 2. 原理 Theory

以下内容摘录改写自项目[huailiang/LipSync: LipSync for Unity3D 根据语音生成口型动画 支持fmod](https://github.com/huailiang/LipSync?tab=readme-ov-file)的Readme.主流的基于MFCC的口型同步算法基本都符合该原理.由于本项目采用的方式是实时匹配,因而删去了烘培的相关原理.

### 2.1 从AudioSource处获取语音数据

从AudioSource处获取是实时匹配时采用的方法.AudioSource本身提供了一个GetOutputData函数,可以获取当前正在播放的语音数据段,过程中也包含了分帧与窗口化的步骤.

### 2.2 剔除无声帧

从信号处理的角度上说,这一步是一种时域分析方法.对数据帧中的所有值进行求和,如果结果大于用户预设的一个阈值(也就是AmplitudeThreshold),那么就认为这一帧是没有声音的,不对它进行后续处理.这可以节省不必要的分析过程.如果适当调高阈值,一定程度上可以降噪.

### 2.3 获取语音数据的频域信息

频域信息指的就是频谱,这对于语音识别来说是非常重要的信息.实时匹配时,AudioSource的`GetSpecturmData`函数带来了极大的帮助,这个函数本身可以高效地获取当前播放的语音数据频谱.

### 2.4 提取共振峰

人在发声时,肺部收缩送出一股直流空气,经器官流至喉头声门处(即声带),使声带产生振动,并且具有一定的振动周期,从而带动原先的空气发生振动,这可以称为气流的激励过程.之后,空气经过声带以上的主声道部分(包括咽喉,口腔)以及鼻道(包括小舌,鼻腔),不同的发音会使声道的肌肉处在不同的部位,这形成了各种语音的不同音色,这可以称为气流在声道的冲激响应过程.

对于语音识别来说,重要的部分是第二个过程,因为"口型"就是声道形状的一部分.而这一冲激响应过程,在频谱上的表现为若干个凸起的包络峰.这些包络峰出现的频率,就被称为"共振峰频率",简称为"共振峰". 一般来说,通过求得一段语音数据的第一,第二共振峰,就可以非常精确地得知这段语音的"元音"是什么.只求第一共振峰,也可以知道大致结果.LipSync的核心步骤正是如此.提取共振峰的方法是,在前一步骤中获取的频谱上求出局部最大值的最大值.

### 2.5 把共振峰映射为元音特征值,进行平滑过渡处理,再赋予到目标对象上

主要是一些映射操作与平滑过渡处理.

## 3. 参考 References

本项目中的口型同步模块参考了项目[hecomi/uLipSync: MFCC-based LipSync plug-in for Unity using Job System and Burst Compiler](https://github.com/hecomi/uLipSync),该项目遵循MIT协议开源.对其中部分代码进行了改写以更契合本项目的需求:

- 删去了本项目无需依赖的部分
- 类名,函数名,变量名调整
- 一些语法上的调整

## 4. 命名空间 Namespace

本项目中所有涉及口型同步的模块均使用`RinaLipSync`命名空间.

## 5. 工具 Tools

该部分为实现口型同步算法提供了一系列工具类型,根路径位于`Assets/Scripts/Tools/RinaLipSync`.

### 5.1 算法 Algorithm

静态类`Algorithm` 提供了一系列语音信号分析和处理的算法以完成语音信号的MFCC特征提取;音频信号处理(如降噪,归一化,频谱分析)等工作.

#### 5.1.1 最大值计算`GetMaxValue`

计算数组中绝对值的最大值,用于快速找到音频信号的最大振幅.

#### 5.1.2 RMS音量计算`GetRMSVolume`

计算音频信号的均方根(RMS)音量,反映信号的总体强度.

#### 5.1.3 循环缓冲区复制`CopyRingBuffer`

实现循环缓冲区的数据复制功能,用于处理循环队列或滑动窗口.

> **圆形缓冲区**(circular buffer),也称作**圆形队列**(circular queue),**循环缓冲区**(cyclic buffer),**环形缓冲区**(ring buffer),是一种用于表示一个固定尺寸,头尾相连的[缓冲区](https://zh.wikipedia.org/wiki/缓冲区)的数据结构,适合缓存[数据流](https://zh.wikipedia.org/wiki/数据流).
>
> 圆形缓冲区的一个有用特性是: 当一个数据元素被用掉后,其余数据元素不需要移动其存储位置.相反,一个非圆形缓冲区(例如一个普通的队列)在用掉一个数据元素后,其余数据元素需要向前搬移.换句话说,圆形缓冲区适合实现[先进先出](https://zh.wikipedia.org/wiki/先進先出演算法)缓冲区,而非圆形缓冲区适合[后进先出](https://zh.wikipedia.org/wiki/後進先出)缓冲区.
>
> 圆形缓冲区适合于事先明确了缓冲区的最大容量的情形.扩展一个圆形缓冲区的容量,需要搬移其中的数据.因此一个缓冲区如果需要经常调整其容量,用链表实现更为合适.
>
> 写操作覆盖圆形缓冲区中未被处理的数据在某些情况下是允许的.特别是在多媒体处理时.例如,音频的生产者可以覆盖掉[声卡](https://zh.wikipedia.org/wiki/声卡)尚未来得及处理的音频数据.
>
> 具体参见 [环形缓冲器 - 维基百科,自由的百科全书](https://zh.wikipedia.org/wiki/環形緩衝區)

#### 5.1.4 归一化处理`Normalize`

将音频信号归一化到特定的范围(默认最大值为1),以标准化数据幅度.

#### 5.1.5 低通滤波器`LowPassFilter`

实现低通滤波器,用于去除音频信号中高频噪声.

>**低通滤波器**(Low-pass filter)容许低频信号通过,但减弱(或减少)频率高于截止频率的信号的通过.对于不同滤波器而言,每个频率的信号的减弱程度不同.当使用在音频应用时,它有时被称为**高频剪切滤波器**,或**高音消除滤波器**.
>
>具体参见 [低通滤波器 - 维基百科,自由的百科全书](https://zh.wikipedia.org/wiki/低通滤波器)

低通滤波器基于**卷积操作**和**窗函数法**进行实现.

**卷积操作**

滤波是通过将原始信号与一个滤波器核(或权重函数)进行卷积运算完成的: 

$$
y[i] = \sum_{j=0}^{n-1} x[i-j] \cdot b[j]
$$

其中: 

- $y[i]$ : 滤波后信号在第 $i$ 点的值.
- $x[i-j]$ : 输入信号对应的点.
- $b[j]$ : 滤波器的系数(也称为卷积核).

**窗函数法**

使用窗函数法构造滤波器系数 `b`.低通滤波器的理想系数基于 **Sinc 函数**: 

$$
\text{Sinc}(x) = \frac{\sin(\pi x)}{\pi x}
$$

但理想滤波器系数是无限长的,为了实际应用,需要使用窗函数如矩形窗对其截断,在有限长度 $n$ 的范围内,计算低通滤波器的系数: 

$$
b[i] = 2 \cdot f_c \cdot \frac{\sin(2\pi f_c x)}{2\pi f_c x}, \quad x = i - \frac{n-1}{2}
$$

- $f_c$ : 归一化的截止频率(范围为0到0.5,表示相对于采样率的一半).
- $n$ : 滤波器核的长度(根据频率范围自动调整).

通过归一化使滤波器满足能量守恒的条件.

#### 5.1.6 降采样`DownSample`

对信号进行降采样,将高采样率数据转换为目标采样率.

**整比例降采样**(`DownSample1`)

整比例降采样直接选择输入信号中等间隔的点.假设采样率为 $f_s$ ,目标采样率为 $f_t$ ,采样率比 $R = \frac{f_s}{f_t}$ ,则输出信号的第 $i$ 个点为: 

$$
y[i] = x[i \cdot R]
$$

其中 $i$ 是输出信号的索引.

**非整比例降采样**(`DownSample2`)

非整比例降采样需要对输入信号进行插值.输出信号点的索引不再是整数,而是浮点数 $f_{\text{index}}$ .插值计算过程包括以下步骤: 

计算目标点的浮点索引: 

$$
f_{\text{index}} = j \cdot \frac{f_s}{f_t}, \quad j = 0, 1, \ldots, N-1
$$

其中 $j$ 是目标采样率下的索引, $N$ 是输出信号长度.

线性插值: 

对于浮点索引 $f_{\text{index}}$,找到最近的两个整数点 $i_0 = \lfloor f_{\text{index}} \rfloor$ 和 $i_1 = i_0 + 1$ ,计算: 

$$
y[j] = (1 - t) \cdot x[i_0] + t \cdot x[i_1]
$$

其中: $t = f_{\text{index}} - i_0$ 是插值因子. $x[i_0], x[i_1]$ 是输入信号在索引 $i_0, i_1$ 的值.

#### 5.1.7 预加重处理`PreEmphasis`

应用预加重滤波器,提高高频部分的能量,用于语音增强和特征提取.

> 预加重是一种在发送端对输入信号高频分量进行补偿的信号处理方式.随着信号速率的增加,信号在传输过程中受损很大,为了在接收终端能得到比较好的信号波形,就需要对受损的信号进行补偿,预加重技术的思想就是在传输线的始端增强信号的高频成分,以补偿高频分量在传输过程中的过大衰减.而预加重对噪声并没有影响,因此有效地提高了输出信噪比.
>
> 理论已经证明,[鉴频器](https://baike.baidu.com/item/鉴频器/5869020?fromModule=lemma_inlink)的输出[噪声功率谱](https://baike.baidu.com/item/噪声功率谱/14723919?fromModule=lemma_inlink)按频率的平方规律增加.但是,许多实际的消息信号,例如语言,音乐等,它们的[功率谱](https://baike.baidu.com/item/功率谱/6463147?fromModule=lemma_inlink)随频率的增加而减小,其大部分能量集中在低频范围内.这就造成消息信号高频端的[信噪比](https://baike.baidu.com/item/信噪比/206685?fromModule=lemma_inlink)可能降到不能容许的程度.但是由于消息信号中较高频率分量的能量小,很少有足以产生最大[频偏](https://baike.baidu.com/item/频偏/6892574?fromModule=lemma_inlink)的幅度,因此产生最大频偏的信号幅度多数是由信号的低频分量引起.平均来说,幅度较小的[高频分量](https://baike.baidu.com/item/高频分量/8356966?fromModule=lemma_inlink)产生的频偏小得多.所以[调频](https://baike.baidu.com/item/调频/771661?fromModule=lemma_inlink)信号并没有充分占用给予它的带宽.因为[调频系统](https://baike.baidu.com/item/调频系统/3243077?fromModule=lemma_inlink)的传输带宽是由需要传送的消息信号([调制信号](https://baike.baidu.com/item/调制信号/10414468?fromModule=lemma_inlink))的最高有效频率和最大频偏决定的.然而,接收端输入的噪声频谱却占据了整个调频带宽.这就是说,在[鉴频器](https://baike.baidu.com/item/鉴频器/5869020?fromModule=lemma_inlink)输出端噪声功率谱在较高频率上已被加重了.
>
> 为了抵消这种不希望有的现象,在调频系统中人们普遍采用了一种叫做预加重和[去加重](https://baike.baidu.com/item/去加重/9028978?fromModule=lemma_inlink)措施,其中心思想是利用信号特性和噪声特性的差别来有效地对信号进行处理.即在噪声引入之前采用适当的网络(预加重网络),人为地加重(提升)发射机输入调制信号的高频分量.然后在接收机鉴频器的输出端,再进行相反的处理,即采用去加重网络把高频分量去加重,恢复原来的信号功率分布.在去加重过程中,同时也减小了噪声的高频分量,但是预加重对噪声并没有影响,因此有效地提高了输出[信噪比](https://baike.baidu.com/item/信噪比/206685?fromModule=lemma_inlink).
>
> 具体参见 [预加重_百度百科](https://baike.baidu.com/item/预加重/9293616)

预加重滤波器通过对当前信号值减去一定比例的前一信号值,构造出一种高通滤波的效果.其数学表达式为: 

$$
y[n] = x[n] - p \cdot x[n-1]
$$

其中: 
- $y[n]$ : 滤波后的输出信号.
- $x[n]$ : 输入信号的当前采样值.
- $p$: 预加重系数(通常取值在 $0.9 \sim 1.0$ ).
- $x[n-1]$ : 输入信号的前一个采样值.

预加重滤波器本质上是一个简单的一阶差分高通滤波器.对于语音信号: 
1. 低频部分: 
   - $x[n]$ 和 $x[n-1]$ 的值相近,差值较小,被削弱.
2. 高频部分: 
   - $x[n]$ 和 $x[n-1]$ 差值较大,高频分量得到增强.

频率响应函数为: 

$$
H(f) = 1 - p \cdot e^{-j2\pi f}
$$

其幅频响应:

$$
|H(f)| = \sqrt{1 - 2p \cos(2\pi f) + p^2}
$$

- 当 $p$ 越接近 1,高频增强效果越显著.
- $f = 0$ 时,增益为 $1 - p$ ,低频被削弱.

预加重系数 $p$ 的选择对滤波效果有重要影响: 
- $p = 0.9 \sim 0.97$ 是常见的取值范围.
- $p$ 越接近 1,增强高频的效果越明显,但可能会导致信号失真.
- 根据应用场景(如安静语音或噪声环境语音)调整 $p$ 值.

#### 5.1.8 汉明窗`HammingWindow`

对信号施加汉明窗,用于减少信号分段时的频谱泄漏.

> **窗函数**(英语: window function)在[信号处理](https://zh.wikipedia.org/wiki/信号处理)中是指一种除在给定[区间](https://zh.wikipedia.org/wiki/区间)之外取值均为0的实[函数](https://zh.wikipedia.org/wiki/函数).譬如: 在给定区间内为[常数](https://zh.wikipedia.org/wiki/常数)而在区间外为0的窗函数被形象地称为**矩形窗**.
>
> 任何函数与窗函数之积仍为窗函数,所以相乘的结果就像透过窗口"看"其他函数一样.窗函数在[频谱](https://zh.wikipedia.org/wiki/頻譜)分析,[滤波器设计](https://zh.wikipedia.org/wiki/滤波器设计),波束形成,以及音频数据压缩(如在[Ogg Vorbis](https://zh.wikipedia.org/wiki/Ogg_Vorbis)音频格式中)等方面有广泛的应用.
>
> 从理论上可以得出函数 $cos⁡(ωt)$ 的[傅立叶变换](https://zh.wikipedia.org/wiki/傅立叶变换)除了在频率 $±ω$ 之外处处为 0.但是许多其它的函数或者波形数据并没有这样方便的闭式变换,或者是我们只对某一时间范围内的频谱数据感兴趣,在这种情况下,就需要对有限时间范围的波形进行傅立叶变换或者其它类似的变换.通常通过波形与一个窗函数的乘积来表示.但是,包括矩形窗在内的所有窗函数都会对待测频谱产生影响.
>
> 当输入波形是采样信号而非连续信号时,傅立叶分析通常对信号应用窗函数并用离散傅立叶变换.但是[离散傅里叶变换](https://zh.wikipedia.org/wiki/离散傅里叶变换)得到的频谱只是[离散时间傅里叶变换](https://zh.wikipedia.org/wiki/离散时间傅里叶变换)频谱的一个粗糙采样.上图是正弦信号应用矩形窗后傅立叶频谱的一部分.位于横轴0点位置的是正弦信号真实频谱,其余频谱均为谱泄漏.频率单位为"DFT bins"(DFT 量化单位)即这些整数值是DFT采样得到的频率.所以该图显示了这样一种情况,正弦信号的实际频率正好与DFT的采样频率一致,并且频谱的最大值通过采样得到.采样错过最大值时的测量误差被称为"扇形损失"(名称源于顶点的形状).但是这种状况下最有趣的是那些与实际频谱相一致的即值为零的那些点.这种情况下,DFT创造了没有泄露的假象.尽管不如本例这样,泄露是DFT中人为引入的也是普遍误解.但是既然任何窗函数都有泄露,那些表面上的不存在泄露才是人为造成的.
>
> 具体参见 [窗函数 - 维基百科,自由的百科全书](https://zh.wikipedia.org/wiki/窗函数)

**Hamming窗与Hann窗**

>$$
>w(n) = a_0 - (1 - a_0) \cdot \cos\left(\frac{2\pi n}{N-1}\right), \quad 0 \leq n \leq N-1
>$$
>
>当  $a_0=0.53836$,称作 **Hamming窗**；当  $a_0=0.5$ 则叫作 **Hann窗**.
>
>**Hann窗**
>
>$$
>w(n)=0.5(1-\cos(\frac{2\pi n}{N-1}))
>$$
>
>[Hann窗](https://zh.wikipedia.org/w/index.php?title=Hann窗&action=edit&redlink=1)有时也称为 "Hanning" 窗("汉宁窗"),以与 Hamming 窗的名称类似.但是这是不对的,因为这两个窗是分别根据 [Julius von Hann](https://zh.wikipedia.org/w/index.php?title=Julius_von_Hann&action=edit&redlink=1) 和 [Richard Hamming](https://zh.wikipedia.org/wiki/Richard_Hamming) 的名字命名的.
>
>Hann窗又称升余弦窗.Hann窗可以看作是3个矩形时间窗的频谱之和,或者说是 3个 $sinc(t)$ 型函数之和,而括号中的两项相对于第一个谱窗向左,右各移动了 $π/T$ ,从而使旁瓣互相抵消,消去高频干扰和漏能.
>
>从减小泄漏观点出发,Hann窗优于矩形窗.但Hann窗主瓣加宽,相当于分析带宽加宽,频率分辨力下降.
>
>**Hamming窗**
>
>$$
>w(n) = 0.53836 - 0.46164 \cdot \cos\left(\frac{2\pi n}{N-1}\right)
>$$
>
>如果我们将  $a_0$ 设为接近 0.53836 的数值,或是更精确来说是 25/46,便会得到Hamming窗,而设定这个数值的用意,是在频率为 $5π/(N − 1)$ 处产生零交会处(zero-crossing),使原先Hann窗的第一个旁瓣(sidelobe)可以被大幅消除,产生只有Hann窗 1/5 高度的旁瓣.
>
>具体参见 [窗函数 - 维基百科,自由的百科全书](https://zh.wikipedia.org/wiki/窗函数)

#### 5.1.9 零填充`ZeroPadding`

在信号两端添加零,扩展信号长度,用于频谱分析等场景.

#### 5.1.10 快速傅里叶变换`FFT`

计算信号的频谱,用于分析信号在频域的分布.

>**快速傅里叶变换**(英语: **Fast Fourier Transform, FFT**),是快速计算序列的[离散傅里叶变换](https://zh.wikipedia.org/wiki/离散傅里叶变换)(DFT)或其逆变换的方法.[傅里叶分析](https://zh.wikipedia.org/wiki/傅里叶分析)将信号从原始域(通常是时间或空间)转换到[频域](https://zh.wikipedia.org/wiki/頻域)的表示或者逆过来转换.FFT会通过把[DFT矩阵](https://zh.wikipedia.org/wiki/離散傅里葉變換矩陣)[分解](https://zh.wikipedia.org/wiki/矩阵分解)为[稀疏](https://zh.wikipedia.org/wiki/稀疏矩阵)(大多为零)因子之积来快速计算此类变换.因此,它能够将计算DFT的[复杂度](https://zh.wikipedia.org/wiki/計算複雜性理論)从只用DFT定义计算需要的 $O(n^2)$ ,降低到 $O(n\log ⁡n)$ ,其中 $n$ 为数据大小.
>
>具体参见 [快速傅里叶变换 - 维基百科,自由的百科全书](https://zh.wikipedia.org/wiki/快速傅里叶变换)

#### 5.1.11 Mel滤波器组`MelFilterBank`

将频谱转换为Mel尺度频谱,用于语音信号的MFCC特征提取.

**Mel尺度变换(从Hz到Mel)**

Mel尺度是一种对频率的非线性变换,它模仿了人耳对不同频率的敏感度.人耳对低频信号的变化更为敏感,而对高频信号的变化则不太敏感.Mel尺度变换使得频率的间隔在低频部分较小,在高频部分较大.

Mel尺度与Hz之间的关系可以通过以下公式表示: 

$$
\text{Mel}(f) = 2595 \cdot \log_{10} \left( 1 + \frac{f}{700} \right)
$$

其中: 
- $f$ 是以赫兹(Hz)为单位的频率；
- $\text{Mel}(f)$ 是对应的Mel频率.

为了从Mel频率转换回Hz频率,使用逆公式: 

$$
f = 700 \cdot \left( 10^{\frac{\text{Mel}(f)}{2595}} - 1 \right)
$$

在代码中,`ToMel` 和 `ToHz` 函数分别执行这两种转换,分别是 **Hz -> Mel** 和 **Mel -> Hz** 的转换.

**Mel频率滤波器组(Mel Filter Bank)**

Mel频率滤波器组用于将原始频谱(通常是FFT频谱)转换到Mel尺度的频谱.滤波器组由多个三角形滤波器组成,每个滤波器对应Mel尺度上的一个频带. `MelFilterBank` 函数通过以下步骤实现了Mel滤波器组的计算: 

- 频率范围设置: 
  - `fMax = sampleRate / 2` 是Nyquist频率,即信号的最大频率.
  - `melMax = ToMel(fMax)` 将Nyquist频率转换为Mel频率.
  
- 频率步长: 
  - `df = fMax / nMax` 是FFT结果中频率的间隔,其中 `nMax = len / 2` 是FFT的长度(假设是对称的,因此只有一半的频谱是有用的).

- Mel频率步长: 
  - `dMel = melMax / (melDiv + 1)` 计算每个Mel滤波器带宽的宽度,其中 `melDiv` 是Mel滤波器的数量.

**滤波器的实现**

对于每个Mel滤波器,它的频率范围由三个值确定: 开始频率( $f_{\mathrm{Begin}}$ ),中心频率( $f_{\text{Center}}$ ) 和结束频率( $f_{\text{End}}$ ),这些频率是Mel尺度上的值.然后这些值会被转换回Hz频率.每个滤波器的形状是一个三角形,并且它的响应是随着频率的变化逐渐增大然后再减小.具体来说: 

- 当频率低于滤波器的中心频率时,滤波器的增益随着频率的增加而线性增加；
- 当频率高于滤波器的中心频率时,增益随着频率的增加而线性减小.

对于每个Mel滤波器,通过以下步骤来计算其权重: 

1. 计算滤波器的增益: 
   - 如果频率小于中心频率,增益线性增加:  $(f - f_{\mathrm{Begin}}) / (f_{\text{Center}} - f_{\mathrm{Begin}})$
   - 如果频率大于中心频率,增益线性减小:  $(f_{\text{End}} - f) / (f_{\text{End}} - f_{\text{Center}})$

2. 归一化: 
   - 为了保持每个滤波器的总能量不变,增益会被标准化: $\frac{1}{0.5 \cdot (f_{\text{End}} - f_{\mathrm{Begin}})}$

3. 加权频谱: 
   - 对于每个滤波器,滤波器的权重与原始频谱中的对应频率相乘,然后累加得到Mel频率谱.

最终,通过将所有滤波器的加权结果累加,得到每个Mel滤波器的输出,作为Mel频谱的最终值.

#### 5.1.12 功率转dB`PowerToDb`

将信号功率转换为分贝(dB)表示,用于更直观的表示信号强度.

#### 5.1.13 Mel-Hz转换`ToMel` 和 `ToHz`

实现频率和Mel尺度之间的互相转换,用于Mel滤波器的设计.

#### 5.1.14 离散余弦变换`DCT`

实现离散余弦变换,用于从Mel频谱生成MFCC特征.

>**离散余弦变换**(英语: **discrete cosine transform, DCT**)是与[傅里叶变换](https://zh.wikipedia.org/wiki/傅里叶变换)相关的一种变换,类似于[离散傅里叶变换](https://zh.wikipedia.org/wiki/离散傅里叶变换),但是只使用[实数](https://zh.wikipedia.org/wiki/实数).离散余弦变换相当于一个长度大概是它两倍的离散傅里叶变换,这个离散傅里叶变换是对一个实[偶函数](https://zh.wikipedia.org/wiki/偶函数)进行的(因为一个实偶函数的傅里叶变换仍然是一个实偶函数),在有些变形里面需要将输入或者输出的位置移动半个单位(DCT有8种标准类型,其中4种是常见的).
>
>离散余弦变换,尤其是它的第二种类型,经常被[信号处理](https://zh.wikipedia.org/wiki/信号处理)和[图像处理](https://zh.wikipedia.org/wiki/图像处理)使用,用于对[信号](https://zh.wikipedia.org/wiki/信号)和[图像](https://zh.wikipedia.org/wiki/图像)进行[有损数据压缩](https://zh.wikipedia.org/wiki/有损数据压缩).这是由于离散余弦变换具有很强的"能量集中"特性: 大多数的信号信息(包括声音和图像)往往集中在离散余弦变换后的低频部分,而且当信号具有接近[马尔可夫过程](https://zh.wikipedia.org/wiki/马尔可夫过程)的统计特性时,离散余弦变换的去相关性接近于[K-L变换](https://zh.wikipedia.org/wiki/K-L变换)(Karhunen-Loève变换——它具有最优的去相关性)的性能.
>
>具体参见 [离散余弦变换 - 维基百科,自由的百科全书](https://zh.wikipedia.org/wiki/离散余弦变换)

#### 5.1.15 范数计算`Norm`

计算信号的二范数,用于量化信号的整体能量.

### 5.2 公共常量 Common

静态类`Common` 提供了一些常量,定义了音频处理和语音同步相关的默认值.

- `AssetName`: 资源名称,用于标识该系统或模块( `rinaLipSync`).
- `DefaultMinVolume` 和 `DefaultMaxVolume`: 音量的默认范围,用于音量归一化或特定阈值的处理.
- `MfccMinValue` 和 `MfccMaxValue`: MFCC的取值范围,用于特征值标准化或处理.

### 5.3 语音同步信息结构 LipSyncInfo
结构体`LipSyncInfo` 用于存储语音同步的中间结果和相关信息.

- `phoneme`: 当前检测到的元音(语音单元).
- `volume`: 归一化后的音量值,用于控制动画或模型的嘴部运动.
- `rawVolume`: 原始音量值,未经过处理的音频输入数据.
- `phonemeRatios`: 存储每个元音的匹配度比例,用于决定最终的元音输出.

### 5.4 口型同步事件 LipSyncUpdateEvent

Unity序列化事件类`LipSyncUpdateEvent`用于触发和处理 `LipSyncInfo` 的更新,主要用于实现松耦合,将语音同步结果传递到其他系统.

### 5.5 音频读取事件 AudioFilterReadEvent

Unity 序列化事件类`AudioFilterReadEvent`用于处理音频数据的实时读取.

- `float[]`: 音频缓冲区,存储当前帧的音频数据.
- `int`: 缓冲区的长度或与音频帧相关的索引.

### 5.6 更新方法枚举 UpdateMethod
枚举`UpdateMethod` 定义语音同步信息更新的触发机制.
- `LateUpdate`: 在每帧结束时更新.
- `Update`: 在每帧的常规更新阶段触发.
- `FixedUpdate`: 在物理更新周期中触发.
- `LipSyncUpdateEvent`: 由事件触发更新.
- `External`: 由外部系统控制更新.

### 5.7 比较方法枚举 CompareMethod
枚举`CompareMethod` 定义元音匹配算法的比较方式.
- `L1Norm`: 基于曼哈顿距离(绝对值差)的匹配方法.
- `L2Norm`: 基于欧几里得距离的匹配方法.
- `CosineSimilarity`: 基于余弦相似度的匹配方法,用于判断两个向量的方向相似性.

### 5.8 口型同步任务系统 LipSyncJob

该任务系统为`Unity.Jobs.IJob`接口的实现,主要功能是基于输入的音频数据,提取特征并匹配元音,确定元音对应的权重以及主要元音的索引.

#### 5.8.1 成员变量
- 输入: 
  - `input`: 输入的原始音频信号.
  - `startIndex`: 音频缓冲区的起始索引,用于处理循环缓冲区.
  - `outputSampleRate` 和 `targetSampleRate`: 输出和目标采样率,用于降采样处理.
  - `melFilterBankChannels`: Mel滤波器组的通道数,用于频谱到Mel频谱的转换.
  - `compareMethod`: 元音匹配的比较方法(L1,L2或余弦相似度).
  - `means` 和 `standardDeviations`: 均值和标准差,用于标准化MFCC特征.
  - `phonemes`: 元音参考数据,存储每个元音的MFCC特征.

- 输出: 
  - `mfcc`: 提取的MFCC特征.
  - `scores`: 每个元音的匹配分数.
  - `info`: 包含音量和主要元音索引的信息.
  - (调试模式下)`debugData`,`debugSpectrum` 等数据用于输出中间处理结果.

#### 5.8.2 主要处理步骤
1. 音频预处理: 
   - 通过`Algorithm.GetRMSVolume`计算音频信号的整体音量.
   - 使用循环缓冲区重排音频数据,并应用低通滤波器去除高频噪声.
   - 将音频降采样到目标采样率,减小计算负担.
   - 应用预加重滤波器强化高频信号.
   - 对音频施加汉明窗减少频谱泄露,并归一化数据.

2. 特征提取: 
   - 使用FFT(快速傅里叶变换)计算频谱.
   - 应用Mel滤波器组将频谱转换为Mel尺度.
   - 将Mel频谱转换为dB(分贝)单位.
   - 通过DCT(离散余弦变换)提取MFCC特征.

3. 元音匹配: 计算每个元音的匹配分数,支持三种匹配方法: 
   - `L1Norm`: 使用绝对值距离计算分数.
   - `L2Norm`: 使用欧几里得距离计算分数.
   - `CosineSimilarity`: 使用余弦相似度计算分数.
   
4. 元音检测: 从匹配分数中选出得分最高的元音,确定主要元音索引.

#### 5.8.3 匹配分数计算
- `CalcL1NormScore`:  计算L1距离(曼哈顿距离),表示MFCC与元音特征之间的绝对值差异.
- `CalcL2NormScore`:  计算L2距离(欧几里得距离),表示MFCC与元音特征的平方差累积.
- `CalcCosineSimilarityScore`:  计算余弦相似度,表示MFCC与元音特征的方向相似性.

### 5.9 MFCC校准数据 MfccCalibrationData

结构体`MfccCalibrationData`主体为一个包含 12 个浮点数的数组,用于表示单个 MFCC 校准数据.提供索引器 (`this[int i]`) 和数组长度 (`Length`) 的访问.

### 5.10 MFCC数据 MfccData

类型`MfccData`用于存储与某个元音相关的 MFCC 数据和其校准信息.包含以下功能: 

- 动态分配和释放内存:  使用 `NativeArray` 管理原生内存(持久化分配).
- 校准数据管理: 
  - `AddCalibrationData`: 添加一组新的 MFCC 校准数据.
  - `RemoveOldCalibrationData`: 移除过多的校准数据,保留一定数量的历史数据.
- 平均值更新: 
  - `UpdateNativeArray`: 基于历史校准数据更新平均值(将结果存储到 `mfccNativeArray`).

### 5.11 识别模型预设配置文件 Profile

类型 `Profile`继承自`UnityEngine.ScriptableObject`,用于保存和管理整个口型同步识别模型的相关配置和数据.

#### 5.11.1 配置选项
该类型提供了一些可以通过 Unity Inspector 面板直接配置的选项: 
- `mfccNum`: MFCC 系数的数量(通常是 12).
- `mfccDataCount`: 用于计算平均值的历史校准数据数量.
- `melFilterBankChannels`: Mel 滤波器组的通道数量.
- `targetSampleRate`: 目标采样率(降采样后).
- `sampleCount`: 降采样后的样本数量.
- `useStandardization`: 是否标准化 MFCC 系数.
- `compareMethod`: 比较元音匹配的方式(L1,L2 或余弦相似度).

#### 5.11.2 数据管理功能
- 数据添加/删除: 
  - `AddMfcc`: 为新元音添加数据.
  - `RemoveMfcc`: 移除指定索引的元音数据.
- 数据更新: 
  - `UpdateMfcc`: 更新指定元音的 MFCC 数据,支持校准模式.
- 数据导入/导出: 
  - `Export` 和 `Import`: 支持将配置导出为 JSON 文件,或从文件中加载.
- 计算平均值和标准差: 
  - `UpdateMeansAndStandardization`: 更新所有元音的均值和标准差.
  - `UpdateMeans` 和 `UpdateStandardizations`: 分别计算均值和标准差.
- 计算最大/最小值: 
  - `CalcMinMax`: 计算所有元音数据的最小值和最大值.

### 5.12 麦克风设备 MicDevice
结构体`MicDevice` 用于存储单个麦克风设备的信息

- `name`: 设备名称.
- `index`: 设备在系统中麦克风设备列表中的索引.
- `minFreq`: 设备支持的最低采样频率.
- `maxFreq`: 设备支持的最高采样频率.

### 5.13 麦克风工具 MicUtil
工具类`MicUtil` 提供了`GetDeviceList` 方法: 

- 遍历系统中所有的麦克风设备.
- 获取每个设备的名称和支持的频率范围.
- 返回一个包含所有麦克风设备信息的 `List<MicDevice>`.

## 6. 组件 Components

该部分调用工具模块,附着在组件上来实现具体的口型同步功能,根路径位于`Assets/Scripts/Components`.

### 6.1 音频源组件 RinaLipSyncAudioSource

`RinaLipSyncAudioSource` 类继承自 `MonoBehaviour`,依赖组件 `AudioSource`.

#### 6.1.1 成员

成员变量为自定义事件 `onAudioFilterRead`,类型为 `AudioFilterReadEvent`.

成员函数为: `OnAudioFilterRead` 

- 参数: 
  - `input`: 包含当前帧的音频样本数据.
  - `channels`: 音频的通道数(例如单声道为1,立体声为2).
- 工作流程: 
  - 在 `AudioSource` 处理音频的每一帧时调用.
  - 将音频数据 `input` 和通道信息 `channels` 转发给 `onAudioFilterRead` 事件的订阅者.

#### 6.1.2 工作流程
1. 当一个 `AudioSource` 播放音频时,Unity 会调用 `OnAudioFilterRead` 方法,并传递当前帧的音频数据.
2. `RinaLipSyncAudioSource` 将捕获的音频数据打包为事件参数,触发 `onAudioFilterRead` 事件.
3. 其他脚本或组件可以通过订阅 `onAudioFilterRead`,实时处理音频数据.

### 6.2 麦克风组件 RinaLipSyncMicrophone

`RinaLipSyncMicrophone`类继承自 `MonoBehaviour`,用于从麦克风捕获音频数据并通过 `AudioSource` 播放,同时提供麦克风管理和音频同步的功能.

#### 6.2.1 功能设计

- 麦克风管理

    - 动态获取麦克风设备: 使用 `MicUtil.GetDeviceList` 获取系统中的麦克风设备列表,并根据指定的索引选择设备.

    - 实时切换设备: 允许在运行时更改当前麦克风设备,并根据需要重新初始化录音.

- 音频捕获与同步

    - 麦克风音频流捕获: 使用 Unity 的 `Microphone.Start` 开始录音,并将录制的数据存储为 `AudioClip`.

    - 音频同步校正: 检测麦克风和 `AudioSource` 播放之间的延迟 (`latency`),并在延迟超出阈值时重新同步.

- 状态管理:通过一系列布尔标志管理麦克风和音频源的状态: 

    - `isRecording`: 是否正在录音.

    - `isReady`: 麦克风是否已初始化.

    - `isStartRequested` 和 `isStopRequested`: 控制录音的启动和停止请求.

- 音频数据处理
    - 提供功能从麦克风捕获的音频创建新的 `AudioClip`,便于后续保存或处理.

#### 6.2.2 成员属性

- `index`: 指定使用的麦克风设备索引.
- `latencyTolerance` 和 `bufferTime`: 用于设置同步的时间阈值和缓冲时间,确保音频流的平滑播放.
- `source` 和 `clip`: 与 `AudioSource` 关联的音频源和音频剪辑.

#### 6.2.3 成员函数

- `StartRecord` 和 `StopRecord`
   - 控制麦克风录音的启动和停止,通过设置请求标志触发实际操作.
   
- `StartRecordInternal`
   - 实际启动麦克风录音,并将录音的 `AudioClip` 设置为 `AudioSource` 的音频剪辑.

- `StopRecordInternal`
   - 停止麦克风录音,停止 `AudioSource` 的播放.

- `UpdateLatencyCheck`
   - 检查麦克风和 `AudioSource` 的延迟是否超出阈值.
   - 如果延迟过大,尝试重新同步或重新启动录音.

- `StopRecordAndCreateAudioClip`
   - 停止录音并创建一个新的 `AudioClip`,将当前捕获的音频数据存储下来,便于后续处理.

### 6.3 口型同步核心组件 RinaLipSync

`RinaLipSync`类继承自 `MonoBehaviour`,是整个口型同步系统的调度中心.

#### 6.3.1 功能设计

- 音频数据捕获: 
  - 从音频源(`RinaLipSyncAudioSource`)接收音频数据.
  - 动态调整缓冲区并管理音频输入.
  
- 特征提取与同步: 
  - 使用 `LipSyncJob` 进行高效的特征提取,包括 MFCC,元音评分等.
  - 将结果计算为 `LipSyncInfo`,包括元音,音量和元音比例.

- 实时校准: 
  - 根据请求更新元音校准数据,使模型能够动态调整和优化.

- 事件驱动: 
  - 使用 `LipSyncUpdateEvent` 将同步结果传递给外部系统.

#### 6.3.2 成员属性
- `profile`: `Profile` 对象,包含音频处理的配置信息(如采样率,MFCC 参数,元音库等).
- `onLipSyncUpdate`: 一个事件,提供给外部系统监听语音同步的实时结果.
- `_rawInputData` 和 `_inputData`: 缓冲区,用于存储音频数据.
- `_mfcc` 和 `_scores`: 存储实时计算的 MFCC 特征和元音评分.
- `_ratios`: 字典,存储每个元音的比例,用于生成口型同步的最终结果.

#### 6.3 成员方法

- 数据捕获

    - `OnDataReceived(float[] input, int channels)`: 
      - 从音频源接收输入数据,存储到 `_rawInputData` 中.
      - 根据 `outputSoundGain` 调整音频增益.
    - `OnAudioFilterRead(float[] input, int channels)`: Unity 的音频回调,用于捕获音频数据流.

- 数据处理

    - `ScheduleJob()`: 
      
      - 调用 `LipSyncJob`,在音频数据上执行特征提取,包括 FFT,MFCC,Mel 滤波等操作.
      - 使用 Unity 的 `Job System` 进行高性能并行计算.
      
      - `UpdateResult()`: 
        - 处理 `LipSyncJob` 的结果,计算主要元音和元音比例.
        - 标准化音量数据,将其映射到 `[0, 1]` 范围.
    
- `InvokeCallback()`: 触发 `onLipSyncUpdate` 事件,将处理结果回调给监听者.

- 校准

    - `RequestCalibration(int index)`: 添加校准请求,指定需要校准的元音索引.

    - `UpdateCalibration()`: 根据校准请求更新元音的 MFCC 数据,以动态调整模型的特征匹配.

- 内存管理
    - `AllocateBuffers()` 和 `DisposeBuffers()`: 动态分配和释放音频缓冲区以及特征提取的中间存储数据.

- 调试与编辑器支持

    - 在调试模式下,支持更多的中间数据(如频谱,Mel 滤波结果)的可视化.

    - 提供 `OnBakeStart` 和 `OnBakeEnd` 方法,用于编辑器模式下的批量处理.

### 6.4 表情管理模块组件 RinaLipSyncFaceManager

`RinaLipSyncFaceManager`类继承自 `MonoBehaviour`,提供了一个回调函数给`RinaLipSync`在口型改变时触发.以便将表情同步到璃奈板硬件上.

#### 6.4.1 功能设计

- 元音驱动表情更新: 根据语音同步系统传递的元音和音量数据,确定当前的表情(口型).
- 表情状态管理: 记录和统计元音历史,稳定元音识别结果,避免频繁切换.
- 通过 UDP 通信控制表情设备: 通过一个 `UdpServer` 将表情数据发送到硬件设备.

#### 6.4.2 成员属性
- `updateMethod`: 表示更新的触发方式,支持 `Update` 和 `LipSyncUpdateEvent` 等选项.
- `volume` 和 `minVolume`: 当前音量及音量的最低阈值,低于此值时嘴巴保持关闭状态.
- `phonemeHistory`: 存储元音历史,用于稳定元音识别结果.
- `faceDict`: 字典,存储元音与对应表情的映射.
- `phonemeCountTable`: 统计元音历史中各元音出现的次数.

#### 6.4.3 成员方法

- `OnLipSyncUpdate(LipSyncInfo info)`: 
  - 接收语音同步系统传递的元音信息,并触发后续更新流程.
  - 如果更新方法是 `LipSyncUpdateEvent`,直接更新口型.

- `UpdateLipSync()`: 
  - 包括音量更新(`UpdateVolume`)和元音更新(`UpdateVowels`).
  - 元音更新基于元音历史统计当前的主要元音,避免识别抖动.

- `Apply()`: 
  - 根据当前元音(`phoneme`)和音量(`volume`),决定是否更新表情.
  - 如果嘴巴需要关闭,切换到默认表情(`"N"`).
  - 如果需要更新表情,通过 `UdpServer` 将表情数据发送给硬件.

#### 6.4.4 方法逻辑设计

- 元音历史统计: 在 `UpdateVowels()` 方法中: 
    1. 将元音记录到 `phonemeHistory`.
    1. 移除过旧的记录,保证历史长度不超过设定的最短持续时间.
    1. 统计 `phonemeHistory` 中每个元音的出现次数,取出现次数最多的元音作为当前元音.

- 表情更新逻辑: 在 `Apply()` 方法中: 
    1. 如果音量低于 `minVolume`: 
       - 关闭嘴巴(`"N"` 表情).
       - 通过 `UdpServer` 更新设备.
    2. 如果音量足够大且元音发生变化: 
        - 更新对应的口型表情(`faceDict`).
        - 将表情数据通过 `UdpServer` 发送到设备.

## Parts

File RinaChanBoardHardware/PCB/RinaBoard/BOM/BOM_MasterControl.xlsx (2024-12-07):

No. | Quantity | Comment | Designator | Footprint | Value
1 | 2 | 0.1uF | C1,C2 | C0603 | 0.1uF
2 | 1 | 1uF | C3 | C0603 | 1uF
3 | 6 | 22uF/25V | C4,C28,C29,C31,C34,C35,C36 | C0603 | 22uF
4 | 2 | 10uF/10V | C8,C9,C30,C37,C38,C39,C41 | C0603 |  | https://item.taobao.com/item.htm?id=561066119649&spm=a1z10.3-c-s.w4002-24706531953.17.776b6a4b7dJCON
6 | 1 | 22pF | C10 | C0603
9 | 1 | 47uF | C40 | C1206 | 47uF | https://item.taobao.com/item.htm?id=635848956132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
10 | 1 | BATTERY | CN1 | CONN-TH_2P-P2.50_HX25003-2A | 2P直
11 | 1 | LED | CN2 | CONN-TH_3P-P2.54_2501S-3P | 3P弯
12 | 1 | DSK34 | D1 | SOD-123_L2.8-W1.8-LS3.7-RD |  | https://item.taobao.com/item.htm?id=545427044723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
13 | 1 | ESD5B5.0ST1G-N | D3 | SOD-523_L1.2-W0.8-LS1.6-BI |  | https://item.taobao.com/item.htm?id=585978688413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
14 | 1 | PUSB3F96X | D7 | DFN2510-10_L2.5-W1.0-P0.50-BL |  | https://item.taobao.com/item.htm?id=696215616154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
15 | 2 | 1uH | L1,L2 | IND-SMD_L7.1-W6.6_MJC-0603T |  | https://item.taobao.com/item.htm?id=528379639825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
16 | 4 | FC-DA1608BK-470H10 | LED1,LED2,LED3,LED4 | LED0603-RD_WHITE |  | https://item.taobao.com/item.htm?id=522573257623
17 | 2 | AO3401A_C347476 | Q2,Q5 | AO3401A_SOT-23-3 |  | https://item.taobao.com/item.htm?id=619514059506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
18 | 2 | S9013-E | Q3,Q4 | SOT-23-3_L2.9-W1.3-P1.90-LS2.4-BR |  | https://item.taobao.com/item.htm?id=522574118071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
19 | 2 | AO3400A_C347475 | Q6,Q7 | AO3400A_SOT-23-3 |  | https://item.taobao.com/item.htm?id=619513547316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
20 | 3 | 0R | R1,R2,R46 | R0603 | 0R | https://item.taobao.com/item.htm?id=584519288165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
21 | 5 | 10k | R3,R4,R29,R42,R44,R5,R8,R25,R26 | R0603 | 10k
23 | 1 | 22K | R9 | R0603
24 | 1 | 100K | R10 | R0603
25 | 1 | 4.7K | R27 | R0603
26 | 1 | 1K | R28 | R0603
27 | 1 | 0.5R | R32 | R0805 | （下一版换0603） | https://item.taobao.com/item.htm?id=522573158122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
28 | 1 | 2R | R33 | R0603 | 2R
29 | 2 | 5.1k | R34,R35 | R0603
30 | 1 | 1M | R36 | R0603
31 | 2 | 10k/nop | R37,R38 | R0603
32 | 1 | 11k | R39 | R0603
33 | 1 | 18k | R40 | R0603
34 | 2 | nop | R41,R45 | R0603
35 | 1 | 1k | R43 | R0603 | 1k
37 | 4 | M2螺丝 | SCREW1,SCREW2,SCREW3,SCREW4 | M2螺丝
38 | 1 | TS-1187A-B-A-B | SW2 | SW-SMD_4P-L5.1-W5.1-P3.70-LS6.5-TL_H1.5 |  | https://item.taobao.com/item.htm?from=cart&id=626265056391&skuId=4683870698146
39 | 4 | Test-Point | TP_EN,TP_GND,TP_GND2,TP_IO0 | Test-Point-0.5mm
40 | 1 | ESP32-S3-WROOM-1-N16R8 | U1 | WIRELM-SMD_ESP32-S3-WROOM-1 |  | https://item.taobao.com/item.htm?id=701482545996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
41 | 1 | CH340C | U2 | SOP-16_L10.0-W3.9-P1.27-LS6.0-BL |  | https://item.taobao.com/item.htm?id=572355836370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
42 | 1 | IP5307 | U4 | ESOP-8_L4.9-W3.9-P1.27-LS6.0-BL-EP | （非优信） | https://item.taobao.com/item.htm?id=775478580682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
43 | 1 | SY8089A1AAC | U5 | TSOT-23-5_L2.9-W1.6-P0.95-LS2.8-BR |  | https://item.taobao.com/item.htm?id=582814885896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
44 | 1 | TYPEC-304-BCP16 | USB1 | USB-C-SMD_TYPEC-304-BCP16 |  | https://item.taobao.com/item.htm?id=573090887123&spm=a1z10.3-c-s.w4002-24706531953.12.3fc66a4b5SBLAH

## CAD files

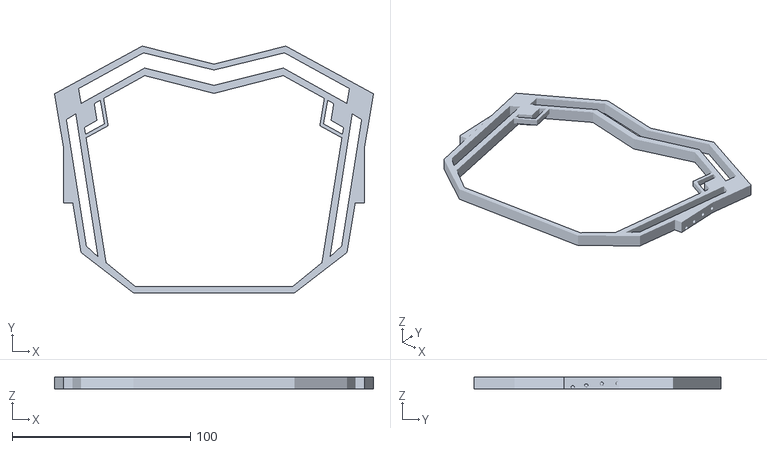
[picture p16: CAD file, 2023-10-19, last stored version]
models/外框.stl
178.7 x 138.2 x 7.00

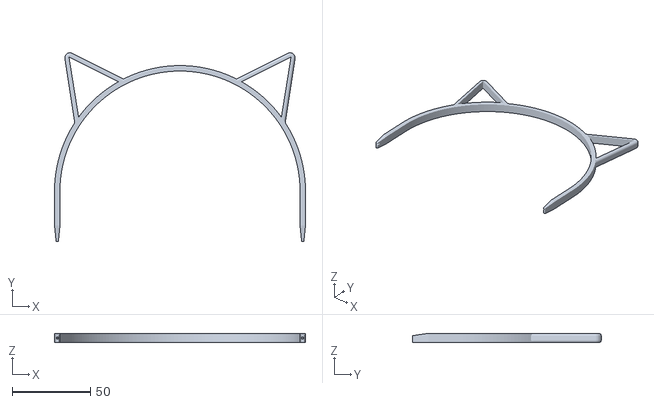
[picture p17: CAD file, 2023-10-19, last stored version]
models/猫耳朵(10cm加长).stl
160.0 x 120.2 x 6.00

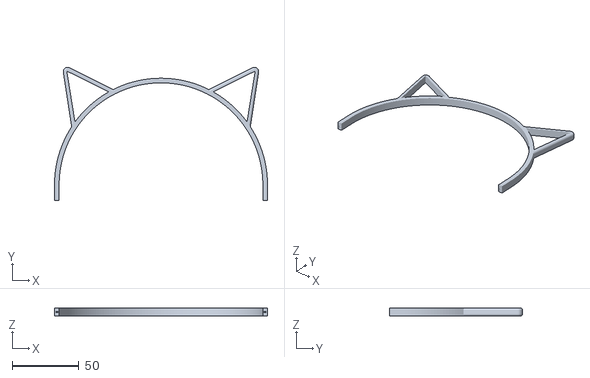
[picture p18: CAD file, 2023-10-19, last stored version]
models/猫耳朵.stl
160.0 x 100.2 x 6.00

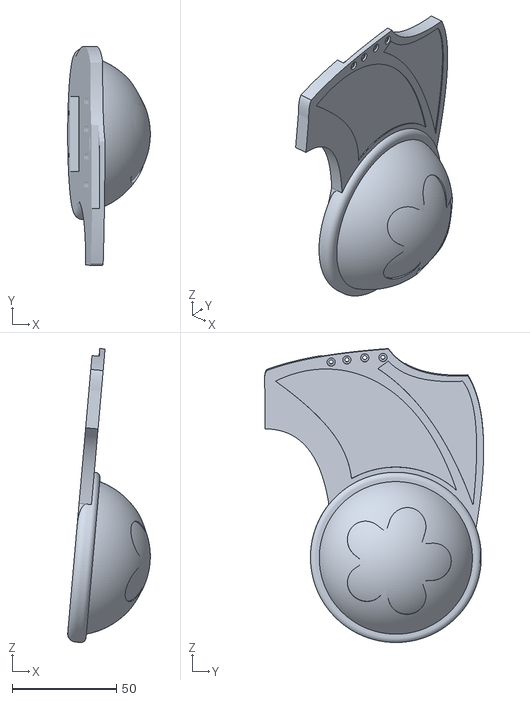
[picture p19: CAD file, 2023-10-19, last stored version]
models/左耳包.stl
39.7 x 105.4 x 141.3

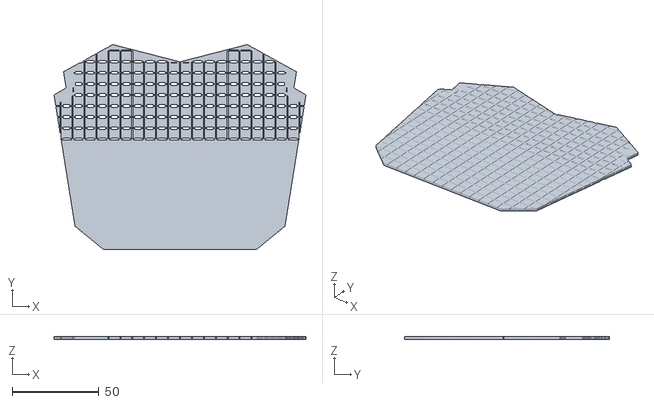
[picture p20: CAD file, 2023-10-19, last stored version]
models/面板.stl
145.4 x 118.2 x 1.80

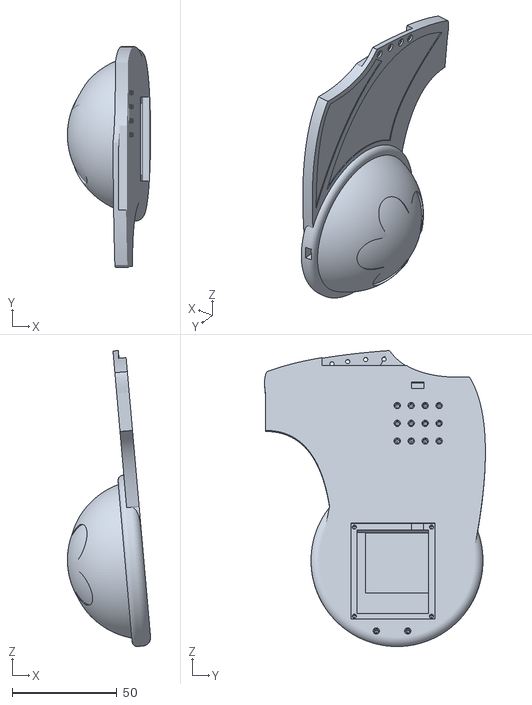
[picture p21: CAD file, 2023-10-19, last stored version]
models/右耳包.stl
39.7 x 105.4 x 141.3

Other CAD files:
models/猫耳朵(5cm加长).stl
models/装配图.f3d

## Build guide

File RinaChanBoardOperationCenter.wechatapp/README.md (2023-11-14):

# 关于RinaChanBoard Operation Center

这是为738NGX's RinaChanBoard特制的微信上位机小程序.

## 📝 技术相关

### 与下位机通讯方式

使用TCP协议,借助巴法云物联网平台实现上位机-下位机之间的通信.当前端发生用户交互时,上位机将适当的指令消息推送到用户选定的主题(即不同的控制机型),下位机接受到来自topic中继的消息后,驱动WS2812B LED灯珠,做出表情变化.

### 不同璃奈板之间的控制方式

巴法云平台可以由用户创建不同的主题(topic)来区分不同的设备.[/utils/util.js](./utils/util.js)文件中的`device_info`数组存放了用户的`uid`和设备的`topic`,通过用户前端进行选择设备来索引数组,即可区分对不同璃奈板之间的消息收发控制.

为了保证璃奈板的正常使用,在切换到不同编号璃奈板的时候会追加密码二次验证.用户需要输入正确的密码后才能取得对应设备的控制权.

### 表情的表示与同步方式

小程序设置了一个16*18的全局数组cells,用于记录每一个位置上LED灯的开闭.同时设置了事件监听器,保证每个页面上的表情显示统一.

虽然很有可能会出现多个上位机控制同一个下位机的情况,但是在现阶段版本中并没有添加从下位机同步当前显示表情到下位机的功能.

### 消息类型

- 自定义表情消息:长度为72的十六进制字符串,可以转换为长度为288的二进制字符串,对应每一个LED灯的开闭信息.
- 预设语音播放消息:长度为16的字符串,记录了语音的id.下位机借助这个id从`std::map`中获取映射的语音表情数据并进行播放.
- 预设歌曲播放消息:长度为19的字符串,记录了歌曲的id.下位机借助这个id从`std::map`中获取映射的歌曲表情数据并进行播放.

## 🕊️ 更新路线图

- 考虑加入一个按钮,可以从下位机上下载当前的表情数据并同步到上位机.手动同步大概可以避免一些可能造成的混乱情况发生
- 考虑添加表情发送按钮到自定义表情界面,将数据上传操作统一管理
- 近期可能会考虑重写歌曲播放逻辑.现在的歌曲播放完全照搬语音的播放逻辑,但是歌曲至少得实现暂停的功能吧(乐)

## ✅ 版本更新记录

加粗部分为重大更新.

| 版本号 | 版本说明 |
| --- | --- |
| 0.0.1 | 第一个测试版本,包含了脱机的自定义表情前端交互. |
| 0.0.2 | 使用TCP协议完成了和下位机的通讯功能,可以正常完成消息收发. |
| 0.0.3 | 首页现在可以显示下位机的连接情况;自定义表情现在已经可以控制脸颊. |
| 0.0.4 | 增加了脱机的预设语音前端交互,虽然现在只包含了一条来自LLAS的测试语音. |
| 0.0.5 | 现在已经可以在首页上选择不同的控制机型(也可以不选择). |
| 0.0.6 | 预设语音的播放消息现在已经可以同步到下位机. |
| 0.0.7 | 增加了脱机的预设歌曲前端交互,包含了测试歌曲Love U my friends(short ver.). |
| 0.0.8 | 预设歌曲的播放消息现在已经可以同步到下位机. |
| 0.0.9 | 增加了两条预设语音. |
| **0.1.0** | **第一个功能基本完备的大版本更新,包括了连接控制/自定义表情/预设语音播放/预设歌曲播放的功能.** |
| 0.1.1 | 修改了自定义表情消息的发送逻辑,现在统一由一个"上传表情"按钮来触发消息发送事件;增加了从璃奈板读取当前显示表情的功能. |
| 0.1.2 | 增加了向璃奈板上传/下载灯珠颜色以及亮度的功能;修改了从璃奈板下载数据时的延迟时间. |
| 0.1.3 | 界面UI显示优化. |

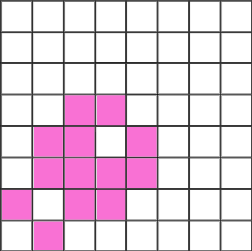
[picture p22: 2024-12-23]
RinaChanBoardOperationCenter/Assets/Resources/Image/FaceModule/120.png

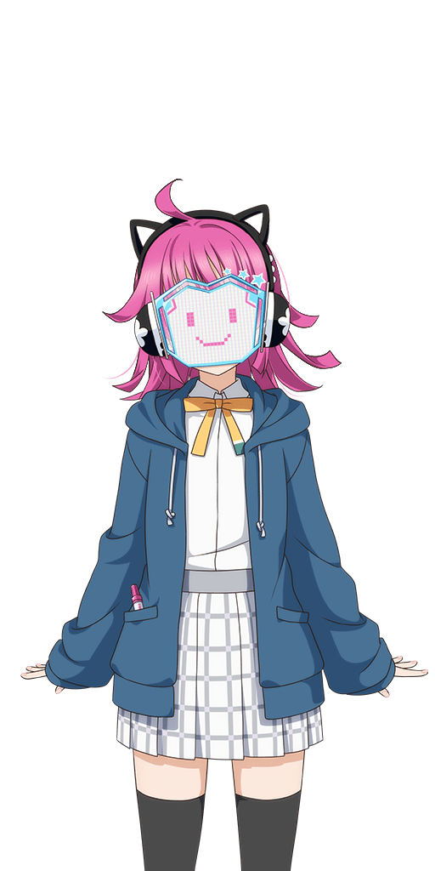
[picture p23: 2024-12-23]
RinaChanBoardOperationCenter/Assets/Resources/Image/Rina/rina-02-c.png

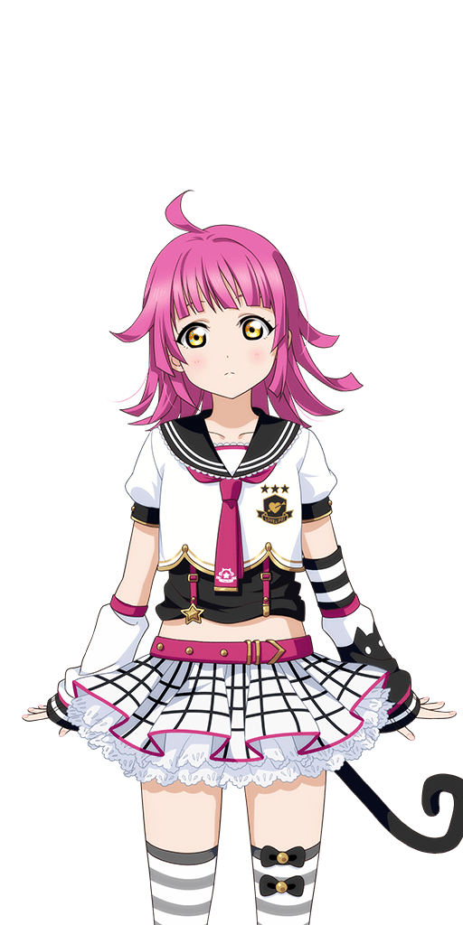
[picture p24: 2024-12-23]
RinaChanBoardOperationCenter/Assets/Resources/Image/Rina/rina-06-uc-wb.png

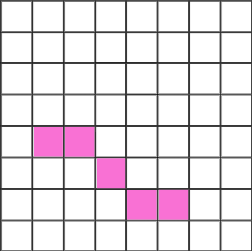
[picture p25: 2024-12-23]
RinaChanBoardOperationCenter/Assets/Resources/Image/FaceModule/115.png

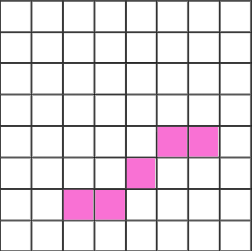
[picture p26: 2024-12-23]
RinaChanBoardOperationCenter/Assets/Resources/Image/FaceModule/215.png

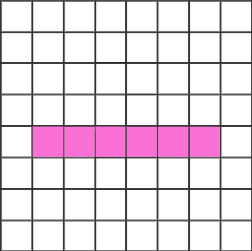
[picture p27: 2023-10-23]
RinaChanBoardOperationCenter/Assets/Resources/Image/FaceModule/301.png

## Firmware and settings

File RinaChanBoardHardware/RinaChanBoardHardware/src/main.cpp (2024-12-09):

#include <ESP8266WiFi.h>
#include <Arduino.h>
#include <FastLED.h>

#include <led.h>
#include <configwifi.h>
#include <udpsocket.h>

CRGB leds[NUM_LEDS];
CRGB def_color(249, 113, 212);
LedUDPHandler udpHandler(leds);
HardwareSerial debugSerial(0);

void setup()
{
    debugSerial.begin(115200, SERIAL_8N1);
    digitalWrite(LED_BUILTIN,HIGH);
    pinMode(DATA_PIN, OUTPUT);
    LEDS.addLeds<LED_TYPE, DATA_PIN, COLOR_ORDER>(leds, NUM_LEDS);
    initLED(leds, def_color);
    debugSerial.println("LED初始化完成,WIFI连接程序开始.");
    WiFi.setSleep(false);
    // esp_wifi_set_ps(WIFI_PS_NONE);

    faceUpdate_StringFullPack("0000000001c0408810040402010000002010000000000033001320040801320033000000", leds, def_color);
    FastLED.show();
    init_wifi_manager();
    faceUpdate_StringFullPack("00000000000000c00630060c02030078000000001400a01e00084002100048000c000000", leds, def_color);
    FastLED.show();
    udpHandler.begin();
    faceUpdate_StringFullPack("00000000000000c00c30030c00c30030000000000000003f000840012000300000000000", leds, def_color);
    FastLED.show();
    end_wifi_manager();
}

void loop()
{
    delay(500); // 空转，防止占用CPU
}

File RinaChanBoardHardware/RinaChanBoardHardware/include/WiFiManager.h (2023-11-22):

/**************************************************************
   WiFiManager is a library for the ESP8266/Arduino platform
   (https://github.com/esp8266/Arduino) to enable easy
   configuration and reconfiguration of WiFi credentials using a Captive Portal
   inspired by:
   http://www.esp8266.com/viewtopic.php?f=29&t=2520
   https://github.com/chriscook8/esp-arduino-apboot
   https://github.com/esp8266/Arduino/tree/master/libraries/DNSServer/examples/CaptivePortalAdvanced
   Built by AlexT https://github.com/tzapu
   Licensed under MIT license
 **************************************************************/

#ifndef WiFiManager_h
#define WiFiManager_h

#include <ESP8266WiFi.h>
#include <ESP8266WebServer.h>
#include <DNSServer.h>
#include <memory>

extern "C" {
  #include "user_interface.h"
}

const char HTTP_HEADER[] PROGMEM          = "<!DOCTYPE html><html lang=\"en\"><head><meta charset=\"UTF-8\"><meta name=\"viewport\" content=\"width=device-width, initial-scale=1, user-scalable=no\"/><title>{v}</title>";
const char HTTP_STYLE[] PROGMEM           = "<style>body{background-image: linear-gradient(-225deg, #FEFEFE 0%, #FFE6FA 100%);background-size : cover;min-height: 100vh;}.c{text-align: center;} div,input{padding:5px;font-size:1em;border-radius:0.5rem;} input{margin-top:0.5rem;margin-bottom:0.5rem;width:95%;} body{text-align: center;font-family:verdana;} button{border:0;border-radius:1rem;background-color:#9ca5b9;color:#fff;line-height:2.4rem;font-size:1.2rem;width:100%;} .q{float: right;width: 64px;text-align: right;} .l{background: url(\"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") no-repeat left center;background-size: 1em;}</style>";
const char HTTP_SCRIPT[] PROGMEM          = "<script>function c(l){document.getElementById('s').value=l.innerText||l.textContent;document.getElementById('p').focus();}</script>";
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

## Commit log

2024-12-05 [refactor](all)项目文件结构调整
    [右耳包.stl, 外框.stl, 左耳包.stl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]
2024-12-05 [typo](doc) 口型同步文档修订
2024-12-05 代码统整
2024-12-05 改为异步UDP
2024-12-05 esp32-s3和clangd的compiler_commands.json的配置
2024-12-05 完成2字节的传输协议回传
2024-12-05 修正串口打印udp、添加弃用函数标签
2024-12-05 传输包完全替换成异步纯hex字节流
2024-12-06 [typo](doc) 文档修订
2024-12-06 减少魔数、规整代码
2024-12-06 新增gen_emojiSet_to_Class.py以自动从.json创建表情集合，并加到了platformio的预编译指令栏。
2024-12-06 把将FACE_FULL和FACE_LITE区分开来，并修改了部分注释
2024-12-06 修复生成class的py文件的问题
2024-12-07 命名统整为大驼峰
2024-12-07 修改部分命名
2024-12-07 修复了下位机更新表情传输错位的问题
2024-12-07 修复了脸颊缺失的问题
2024-12-07 修正左脸颊错位
2024-12-07 预留一个存储版本号的文件
2024-12-07 规整代码
2024-12-07 添加滚动文字小包预留位，offset确认可用，等待上位机联调
2024-12-07 初版PCB，准备改第二版
    [BOM_MasterControl.xlsx]
2024-12-08 加入版本号回传功能
2024-12-08 原理图小改
2024-12-08 修正typo
2024-12-08 添加对旧版esp32的编译支持
2024-12-08 [feature] 文档更新
2024-12-08 [refactor] 测试平台重构
2024-12-08 [typo] README更新
2024-12-09 [typo] 修正颜色RB回传传反的问题
2024-12-09 [refactor] 同步更新ESP8266的固件
2024-12-12 修复face_full后接face_text的残留bug
2024-12-23 上位机代码合并更新
